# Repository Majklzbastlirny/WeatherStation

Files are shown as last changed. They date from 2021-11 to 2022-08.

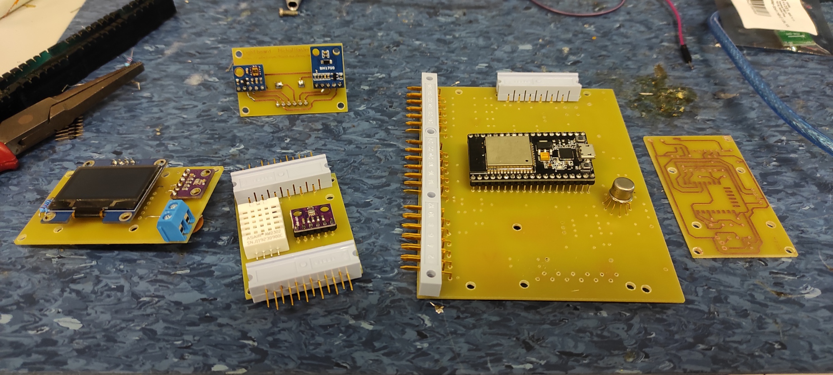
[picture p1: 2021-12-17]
Hardware/PCBs and other pcb stuff/IMG_20211216_153734.jpg

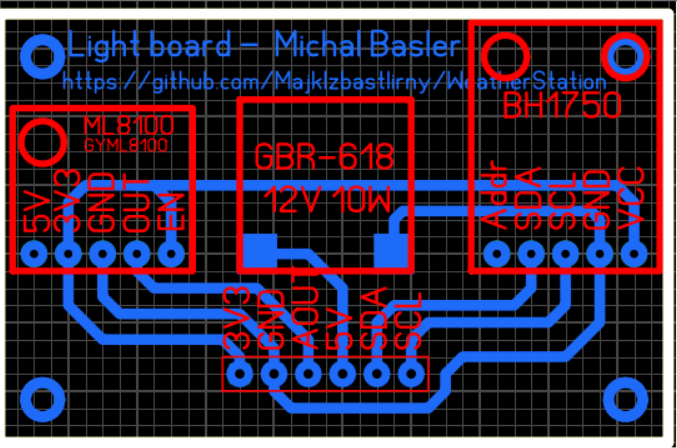
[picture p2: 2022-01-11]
Hardware/PCBs and other pcb stuff/Light board.png

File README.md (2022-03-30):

# WeatherStation
# NEEDS ESP32 ver. 2.0.0 (as Arduino board) otherwise light sensor will NOT work
Weather Station with ESP32, ESP8266, MQTT, InfluxDB and Grafana.

This is my maturita (finals) project.

Public API: https://weatherapi.majkl.tk

Public dashboard https://grafana.majkl.tk

Twitter (new data uploaded every second hour): https://twitter.com/majklzbastlirny

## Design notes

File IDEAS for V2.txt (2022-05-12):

LoRa/LoRaWan - 4 msg/hour https://avbentem.github.io/airtime-calculator/ttn/eu868/180,15
hybrid approach, software update ONLY local (station - Display), data publishing LoRaWan and Local lora to RPI (Display & DB unit)
Light sensor - VEML7700 (Vishay)
Humidity, Pressure, temperature - BME680(688) (Bosch sensortek)

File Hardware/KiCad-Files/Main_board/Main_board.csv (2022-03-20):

Source:,"C:\Users\Michal\Documents\GitHub\WeatherStation\Hardware\KiCad-Files\Main_board\Main_board.kicad_sch"
Date:,"20.03.2022 18:25:14"
Tool:,"Eeschema (6.0.0)"
Generator:,"C:\Program Files\KiCad\6.0\bin\scripting\plugins/bom_csv_grouped_by_value.py"
Component Count:,"46"
Individual Components:
 | Oznaèení | Hodnota | Název | Typ | Vırobce | Velikost
Item,"Qty","Reference(s)","Value","LibPart","Footprint","Datasheet" | B1 | 380V~/1,5A | Usmìròovaè |  |  | 9mm
,"","B1","RB1A","Main_board-eagle-import:RB1A","Diode_THT:Diode_Bridge_Round_D9.0mm","" | C1-C3 | 1mF | Elektrolityckı
,"","C1","1m","Main_board-eagle-import:CPOL-EUE2,5-6E","Capacitor_THT:CP_Radial_D12.5mm_P7.50mm","" | C4-C5 | 100nF | Keramickı kondenzátor
,"","C2","1m","Main_board-eagle-import:CPOL-EUE2,5-6E","Capacitor_THT:CP_Radial_D12.5mm_P7.50mm","" | D1-D3 | 1kV/1A | Schottkyho dioda | UF4007GP | Diotec Semiconductor
,"","C3","1m","Main_board-eagle-import:CPOL-EUE2,5-6E","Capacitor_THT:CP_Radial_D12.5mm_P7.50mm","" | R1-R7 | 43R | Metalizovanı odpor | TR191 | Tesla
,"","C4","100n","Device:C","Capacitor_THT:C_Axial_L5.1mm_D3.1mm_P12.50mm_Horizontal","~" | R8 | 9k1 | Metalizovanı odpor | TR191 | Tesla
,"","C5","100n","Device:C","Capacitor_THT:C_Axial_L5.1mm_D3.1mm_P12.50mm_Horizontal","~" | R9 | 12k | Metalizovanı odpor | TR191 | Tesla
,"","D1","1N581","Main_board-eagle-import:1N581","Diode_THT:D_A-405_P7.62mm_Horizontal","" | R10 | 130R | Metalizovanı odpor | TR191 | Tesla
,"","D2","1N581","Main_board-eagle-import:1N581","Diode_THT:D_A-405_P7.62mm_Horizontal","" | R11 | 90k9 | Metalizovanı odpor | TR191 | Tesla
,"","D3","1N581","Main_board-eagle-import:1N581","Diode_THT:D_A-405_P7.62mm_Horizontal","" | R12 | 464R | Metalizovanı odpor | TR191 | Tesla
,"","F1","2A","Main_board-eagle-import:SH25","Fuse:Fuseholder_Cylinder-5x20mm_Stelvio-Kontek_PTF78_Horizontal_Open","" | X1 |  | Wago svorka x2 |  | Wago
,"","F2","2A","Main_board-eagle-import:SH25","Fuse:Fuseholder_Cylinder-5x20mm_Stelvio-Kontek_PTF78_Horizontal_Open","" | X2,X3 |  | WK konektor samec |  | Tesla
,"","JP1","PINHD-1X1","Main_board-eagle-import:PINHD-1X1","Connector_Pin:Pin_D0.7mm_L6.5mm_W1.8mm_FlatFork","" | X4 |  | WK konektor samec trojnásobnı |  | Tesla
,"","JP2","PINHD-1X1","Main_board-eagle-import:PINHD-1X1","Connector_Pin:Pin_D0.7mm_L6.5mm_W1.8mm_FlatFork","" | LED1-LED8 | 10mA/2,5V | Zelená LED | VQA25 | Tesla
,"","JP3","PINHD-1X1","Main_board-eagle-import:PINHD-1X1","Connector_Pin:Pin_D0.7mm_L6.5mm_W1.8mm_FlatFork","" | F1-F2 | 2A-F | Pojistkové pouzdro
,"","JP4","PINHD-1X1","Main_board-eagle-import:PINHD-1X1","Connector_Pin:Pin_D0.7mm_L6.5mm_W1.8mm_FlatFork","" | Q1 |  | N-Mosfet
,"","JP5","PINHD-1X1","Main_board-eagle-import:PINHD-1X1","Connector_Pin:Pin_D0.7mm_L6.5mm_W1.8mm_FlatFork","" | U1 |  | ESP32-Devkit |  | Espressif
,"","LED1","LEDB152","Main_board-eagle-import:LEDB152","LED_THT:LED_D1.8mm_W3.3mm_H2.4mm","" | U2 |  | TSR1-2450 |  | Traco
,"","LED2","LEDB152","Main_board-eagle-import:LEDB152","LED_THT:LED_D1.8mm_W3.3mm_H2.4mm","" | U3 |  | Buck mìniè s LM2596
,"","LED3","LEDB152","Main_board-eagle-import:LEDB152","LED_THT:LED_D1.8mm_W3.3mm_H2.4mm",""
,"","LED4","LEDB152","Main_board-eagle-import:LEDB152","LED_THT:LED_D1.8mm_W3.3mm_H2.4mm",""
,"","LED5","LEDB152","Main_board-eagle-import:LEDB152","LED_THT:LED_D1.8mm_W3.3mm_H2.4mm","" | SV1 |  | WK konektor samec |  | Tesla
,"","LED6","LEDB152","Main_board-eagle-import:LEDB152","LED_THT:LED_D1.8mm_W3.3mm_H2.4mm","" | SV2-4 |  | WK konektor samec |  | Tesla
,"","LED7","LEDB152","Main_board-eagle-import:LEDB152","LED_THT:LED_D1.8mm_W3.3mm_H2.4mm","" | SV5 |  | WK konektor samec |  | Tesla
,"","LED8","LEDB152","Main_board-eagle-import:LEDB152","LED_THT:LED_D1.8mm_W3.3mm_H2.4mm","" | X1 |  | Wago svorka x2 |  | Wago
,"","Q1","N-MOSFET","Main_board-eagle-import:MOSFET-NGDS_TO220V","Package_TO_SOT_THT:TO-220-3_Horizontal_TabDown",""
,"","R1","43R","Main_board-eagle-import:R-EU_0207{slash}10","Resistor_THT:R_Axial_DIN0207_L6.3mm_D2.5mm_P10.16mm_Horizontal",""
,"","R2","43R","Main_board-eagle-import:R-EU_0207{slash}10","Resistor_THT:R_Axial_DIN0207_L6.3mm_D2.5mm_P10.16mm_Horizontal",""
,"","R3","43R","Main_board-eagle-import:R-EU_0207{slash}10","Resistor_THT:R_Axial_DIN0207_L6.3mm_D2.5mm_P10.16mm_Horizontal",""
,"","R4","43R","Main_board-eagle-import:R-EU_0207{slash}10","Resistor_THT:R_Axial_DIN0207_L6.3mm_D2.5mm_P10.16mm_Horizontal",""
,"","R5","43R","Main_board-eagle-import:R-EU_0207{slash}10","Resistor_THT:R_Axial_DIN0207_L6.3mm_D2.5mm_P10.16mm_Horizontal",""
,"","R6","43R","Main_board-eagle-import:R-EU_0207{slash}10","Resistor_THT:R_Axial_DIN0207_L6.3mm_D2.5mm_P10.16mm_Horizontal",""
,"","R7","43R","Main_board-eagle-import:R-EU_0207{slash}10","Resistor_THT:R_Axial_DIN0207_L6.3mm_D2.5mm_P10.16mm_Horizontal",""
,"","R8","9k1","Main_board-eagle-import:R-EU_0207{slash}10","Resistor_THT:R_Axial_DIN0207_L6.3mm_D2.5mm_P10.16mm_Horizontal",""
,"","R9","12k","Main_board-eagle-import:R-EU_0207{slash}10","Resistor_THT:R_Axial_DIN0207_L6.3mm_D2.5mm_P10.16mm_Horizontal",""
,"","R10","130R","Main_board-eagle-import:R-EU_0207{slash}10","Resistor_THT:R_Axial_DIN0207_L6.3mm_D2.5mm_P10.16mm_Horizontal",""
,"","R11","90K9","Main_board-eagle-import:R-EU_0207{slash}10","Resistor_THT:R_Axial_DIN0207_L6.3mm_D2.5mm_P10.16mm_Horizontal",""
,"","R12","464R","Main_board-eagle-import:R-EU_0207{slash}10","Resistor_THT:R_Axial_DIN0207_L6.3mm_D2.5mm_P10.16mm_Horizontal",""
,"","SV1","MA12-1","Main_board-eagle-import:MA12-1","Connector_PinHeader_2.54mm:PinHeader_1x12_P2.54mm_Horizontal",""
,"","SV2","MA12-1","Main_board-eagle-import:MA12-1","Connector_PinHeader_2.54mm:PinHeader_1x12_P2.54mm_Horizontal",""
,"","SV3","MA12-1","Main_board-eagle-import:MA12-1","Connector_PinHeader_2.54mm:PinHeader_1x12_P2.54mm_Horizontal",""
,"","SV4","MA12-1","Main_board-eagle-import:MA12-1","Connector_PinHeader_2.54mm:PinHeader_1x12_P2.54mm_Horizontal",""
,"","SV5","MA12-1","Main_board-eagle-import:MA12-1","Connector_PinHeader_2.54mm:PinHeader_1x12_P2.54mm_Horizontal",""
,"","U1","ESP32-DEVKITC-32D","Main_board-eagle-import:ESP32-DEVKITC-32D","ESP32:MODULE_ESP32-DEVKITC-32D",""
,"","U2","TSR1-2450","Main_board-eagle-import:TSR1-2450","Converter_DCDC:Converter_DCDC_RECOM_R-78E-0.5_THT",""
,"","U3","Buck_converter-LM2596","Buck_Converter:Buck_converter-LM2596","",""
,"","X1","W237-102","Main_board-eagle-import:W237-102","TerminalBlock_WAGO:TerminalBlock_WAGO_236-102_1x02_P5.00mm_45Degree",""
Collated Components:
Item,"Qty","Reference(s)","Value","LibPart","Footprint","Datasheet"
1,"1","B1","RB1A","Main_board-eagle-import:RB1A","Diode_THT:Diode_Bridge_Round_D9.0mm",""
2,"3","C1, C2, C3","1m","Main_board-eagle-import:CPOL-EUE2,5-6E","Capacitor_THT:CP_Radial_D12.5mm_P7.50mm",""
3,"2","C4, C5","100n","Device:C","Capacitor_THT:C_Axial_L5.1mm_D3.1mm_P12.50mm_Horizontal","~"
4,"3","D1, D2, D3","1N581","Main_board-eagle-import:1N581","Diode_THT:D_A-405_P7.62mm_Horizontal",""
5,"2","F1, F2","2A","Main_board-eagle-import:SH25","Fuse:Fuseholder_Cylinder-5x20mm_Stelvio-Kontek_PTF78_Horizontal_Open",""
6,"5","JP1, JP2, JP3, JP4, JP5","PINHD-1X1","Main_board-eagle-import:PINHD-1X1","Connector_Pin:Pin_D0.7mm_L6.5mm_W1.8mm_FlatFork",""
7,"8","LED1, LED2, LED3, LED4, LED5, LED6, LED7, LED8","LEDB152","Main_board-eagle-import:LEDB152","LED_THT:LED_D1.8mm_W3.3mm_H2.4mm",""
8,"1","Q1","N-MOSFET","Main_board-eagle-import:MOSFET-NGDS_TO220V","Package_TO_SOT_THT:TO-220-3_Horizontal_TabDown",""
9,"7","R1, R2, R3, R4, R5, R6, R7","43R","Main_board-eagle-import:R-EU_0207{slash}10","Resistor_THT:R_Axial_DIN0207_L6.3mm_D2.5mm_P10.16mm_Horizontal",""
10,"1","R8","9k1","Main_board-eagle-import:R-EU_0207{slash}10","Resistor_THT:R_Axial_DIN0207_L6.3mm_D2.5mm_P10.16mm_Horizontal",""
11,"1","R9","12k","Main_board-eagle-import:R-EU_0207{slash}10","Resistor_THT:R_Axial_DIN0207_L6.3mm_D2.5mm_P10.16mm_Horizontal",""
12,"1","R10","130R","Main_board-eagle-import:R-EU_0207{slash}10","Resistor_THT:R_Axial_DIN0207_L6.3mm_D2.5mm_P10.16mm_Horizontal",""
13,"1","R11","90K9","Main_board-eagle-import:R-EU_0207{slash}10","Resistor_THT:R_Axial_DIN0207_L6.3mm_D2.5mm_P10.16mm_Horizontal",""
14,"1","R12","464R","Main_board-eagle-import:R-EU_0207{slash}10","Resistor_THT:R_Axial_DIN0207_L6.3mm_D2.5mm_P10.16mm_Horizontal",""
15,"5","SV1, SV2, SV3, SV4, SV5","MA12-1","Main_board-eagle-import:MA12-1","Connector_PinHeader_2.54mm:PinHeader_1x12_P2.54mm_Horizontal",""
16,"1","U1","ESP32-DEVKITC-32D","Main_board-eagle-import:ESP32-DEVKITC-32D","ESP32:MODULE_ESP32-DEVKITC-32D",""
17,"1","U2","TSR1-2450","Main_board-eagle-import:TSR1-2450","Converter_DCDC:Converter_DCDC_RECOM_R-78E-0.5_THT",""
18,"1","U3","Buck_converter-LM2596","Buck_Converter:Buck_converter-LM2596","",""
19,"1","X1","W237-102","Main_board-eagle-import:W237-102","TerminalBlock_WAGO:TerminalBlock_WAGO_236-102_1x02_P5.00mm_45Degree",""

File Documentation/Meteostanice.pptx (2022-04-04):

## Meteostanice

Michal Basler E4 – 2021/2022

## Co vše v téhle prezentaci bude?

- Průběh práce
- Popis jednotlivých součástí
- Popis kódu
- Výsledek

## Jak práce probíhala

- Prototypování na nepájivém poli
- Nakreslení desek a jejich osazení
- Zkouška všech modulů
- Tisk fyzických součástí
- Složení a oživení

## Co stanice umí měřit

- Stanice umí měřit teplotu, absolutní tlak, relativní vlhkost, UV intenzitu, světelnou intenzitu, směr větru a rychlost větru.
- Dále umí vypočítat pocitovou teplotu, rosný bod, relativní tlak a větrný chlad

## Anemometr

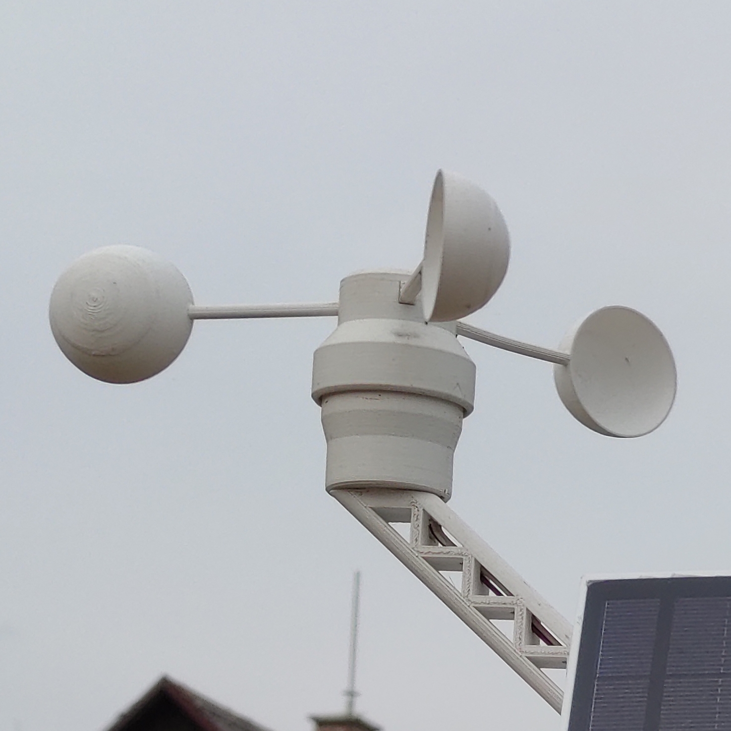
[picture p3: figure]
Anemometr, který je nachází v práci.
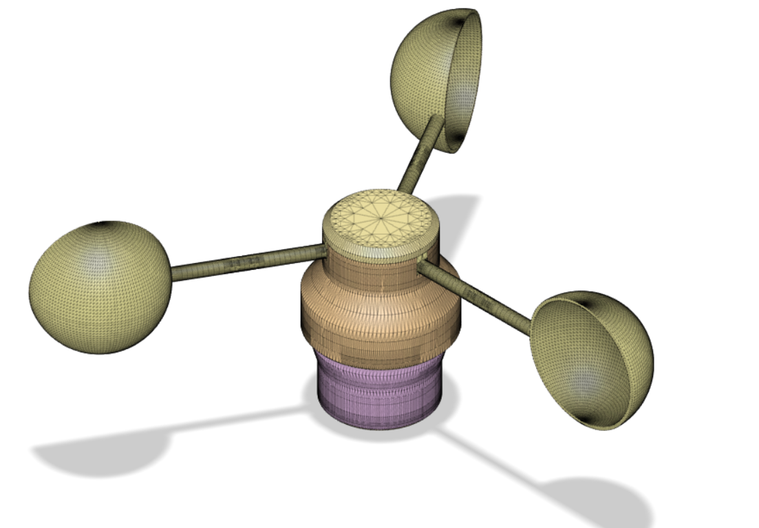
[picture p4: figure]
3D model anemometru

## Korouhev

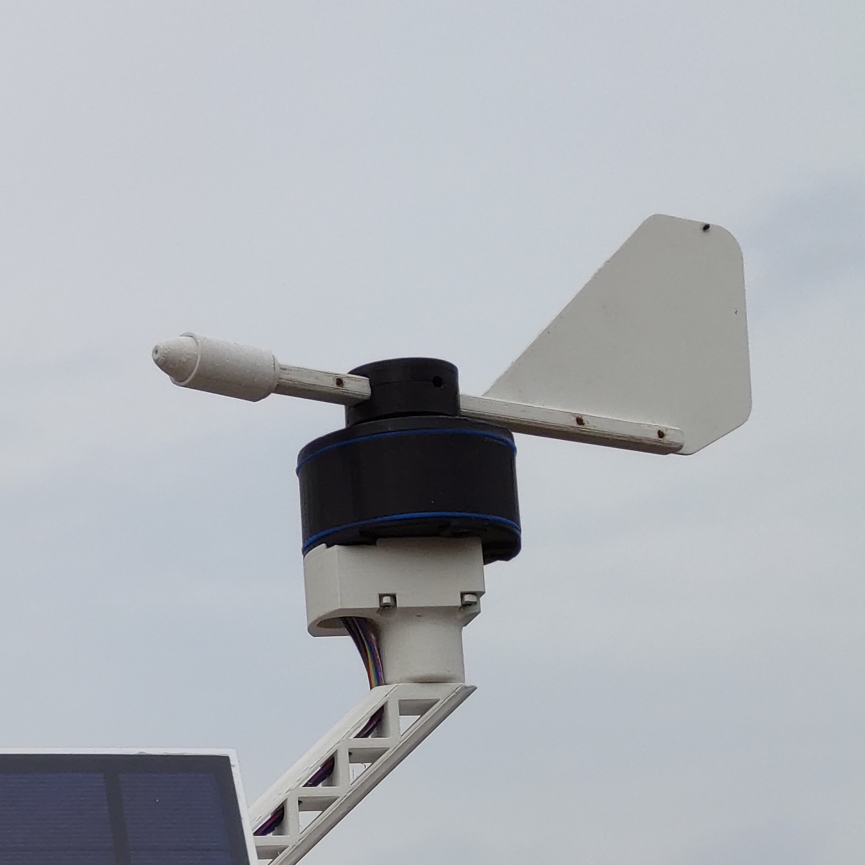
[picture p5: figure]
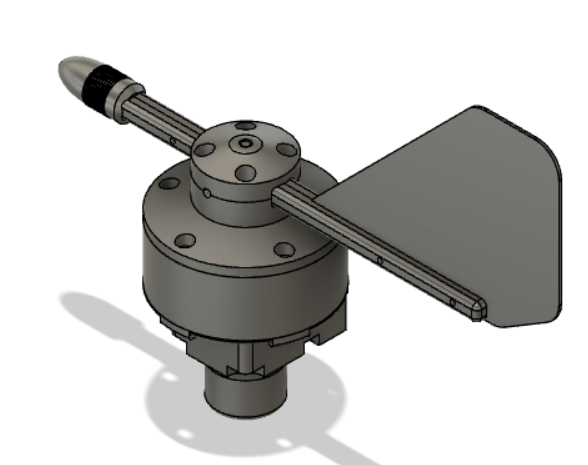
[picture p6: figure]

## Senzory

## Deska senzorů 1

## Deska senzorů 2

## Popis fungování stanice

## Popis fungování zobrazovačů

## Grafana

## API

## Twitter bot

## Výsledek

## Shrnutí

## Díky za pozornost

- Nyní nastal čas na Vaše otázky

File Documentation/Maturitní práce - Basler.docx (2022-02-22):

Vyšší odborná škola a Střední průmyslová škola, Šumperk

Gen. Krátkého 1, 787 29 Šumperk

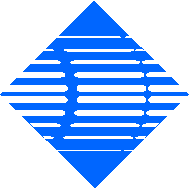
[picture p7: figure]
LOGO

Obor vzdělání: 26-41-M/01 Elektrotechnika

MATURITNÍ PRÁCE

Meteostanice

Školní rok 2021/2022 Michal Basler

Vyšší odborná škola a Střední průmyslová škola, Šumperk,

Gen. Krátkého 1, 787 29 Šumperk

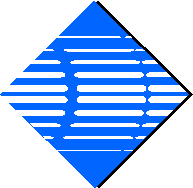
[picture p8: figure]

Obor vzdělání: 26-41-M/01 Elektrotechnika

ZADÁNÍ MATURITNÍ PRÁCE

z odborných předmětů

Žák/Žákyně: Michal Basler

Téma maturitní práce: Meteostanice

Obsah maturitní práce: 1. Základní informace

2. Elektronika a zapojení

3. Kód

Datum zadání: 30. září 2021

Datum odevzdání: 25. března 2022

Vedoucí práce: PaedDr. SOURAL Martin, MBA Podpis:

Prohlášení

Prohlašuji, že jsem svou maturitní práci vypracoval samostatně a použil jsem pouze prameny a literaturu uvedené v seznamu bibliografických záznamů.

Prohlašuji, že tištěná verze a elektronická verze maturitní práce jsou shodné.

Nemám závažný důvod proti zpřístupňování této práce v souladu se zákonem č. 121/2000 Sb., o právu autorském, o právech souvisejících s právem autorským a o změně některých zákonů (autorský zákon) ve znění pozdějších předpisů.

V Šumperku dne datum ……………………………………………………

Michal Basler

Poděkování

Děkuji všem, co mi nepomohli

Vyšší odborná škola a Střední průmyslová škola, Šumperk,

Gen. Krátkého 1, 787 29 Šumperk

KONZULTAČNÍ LIST

Žák/Žákyně: Michal Basler Třída: E4

Téma maturitní práce: Meteostanice

_________________________________________________________________________

Datum kontroly: _________________

Obsah kontroly: ________________________________________________________

Hodnocení kontroly: 1 2 3 4 5 Podpis vedoucího práce: ________

Datum kontroly: _________________

Obsah kontroly: ________________________________________________________

Hodnocení kontroly: 1 2 3 4 5 Podpis vedoucího práce: ________

Datum kontroly: _________________

Obsah kontroly: ________________________________________________________

Hodnocení kontroly: 1 2 3 4 5 Podpis vedoucího práce: ________

Datum kontroly: _________________

Obsah kontroly: ________________________________________________________

Hodnocení kontroly: 1 2 3 4 5 Podpis vedoucího práce: ________

Datum kontroly: _________________

Obsah kontroly: ________________________________________________________

Hodnocení kontroly: 1 2 3 4 5 Podpis vedoucího práce: ________

Obsah vygenerujte!

# 1 Úvod

Práce se zabývá návrhem, výrobou, konstrukcí a zprovozněním poloprofesionální meteostanice vyrobené s použitím to 3D tisku.

Meteostanice by měla umět měřit základní veličiny a to teplota, tlak, vlhkost, rychlost větru, směr větru, UV intenzitu a světlo. Meteostanice by z naměřených jednotek měla také odvodit rosný bod, pocitovou teplotu a relativní tlak.

Cílem mé maturitní práce je zprovoznění meteostanice a zveřejnění měřených dat na internet.

# 2 Meteorologická stanice

Meteorologické stanice jsou zařízení, které umožňují lidem zjišťovat aktuální a budoucí počasí.

Ve většině domácností se tahle zařízení nacházejí, ale umí měřit pouze základní údaje jako je teplota, vlhkost a tlak. Navíc také data zobrazují pouze na jednoúčelových obrazovkách a není zde možnost je zobrazit třeba na mobilním telefonu.

Profesionální stanice měří navíc i rychlost a směr větru, UV záření, sluneční záření, množství srážek, množství oblačnosti a mnoho dalších jevů.

## 2.1 Druhy senzorů

Zde popíšu principy a zařízení, kterými se měří jednotlivé veličiny. Z důvodu, že se jedná o elektrické zařízení, budou zde jmenováno pouze elektrická měření těchto veličin.

### Teploměr

Teplotu lze změřit mnoha různými způsoby. Mezi ně patří třeba měření pozistorem, termočlánkem, negistorem anebo polovodičem. Negistoru se při rostoucí teplotě snižuje odpor. U pozistorů odpor naopak roste. U termočlánků se při rostoucí teplotě zvyšuje proud. Termočlánky se skládají ze dvou různých kovů. Díky tomu termočlánky vydrží i velice vysoké teploty.

### Vlhkoměr

Čistě elektronicky lze měřit relativní vlhkost pouze kapacitně a odporově. U kapacitních se uvnitř nachází dvě elektrody a oddělující vrstva z hygroskopického materiálu. Mezi elektrodami se měří napětí, a to je dále posíláno na zpracovaní na užitečný údaj. U odporových vlhkoměrů se mění odpor v závislosti na vlhkosti. Uvnitř se nachází materiál, který absorbuje vlhkost a přes něj se měří odpor. Výsledná jednotka je udávána jako relativní vlhkost v %.

### Tlakoměr

Tlak lze elektronicky změřit mnoha způsoby. Jednou z nejrozšířenější metod měření tlaku je měření tenzometrem. Jedná se o tenkou kovovou folii přilepenou na membránu. Membrána se pohybuje v závislosti na tlaku a tím se pohybuje i kovová folie. Na ní se měří odpor a ten je následně převáděn tlak. Měřit tlak lze i za pomocí piezorezistivního tenzometru. Využívá se piezoelektrického efektu.

### Anemometr

Anemometr, anebo měřič rychlosti větru se používá na měření rychlosti větru. Elektronicky lze rychlost větru měřit buď dynamem, anebo „tachometrem“. U měření rychlosti dynamem se používá malý motorek jako generátor. V závislosti na rychlosti větru se generuje napětí. Generované napětí je převáděno pomocí A/D převodníku na signál, který lze už převést na rychlost větru. U měření rychlosti „tachometrem“ se používá v anemometru magnet a Hallova sonda nebo jazýčkové relé. Při jednom otočení magnet aktivuje Hallovu sondu anebo jazýčkové relé. Mikropočítač tyto impulzy vezme a s pomocí průměru anemometru vypočítá přesně rychlost větru.

### Větrná korouhev

Větrná korouhev se používá k určení směru větru. Vítr natáčí korouhví a vnitřní obvody detekují směr větru. Směr lze detekovat buď pomocí mnoha jazýčkových relé nebo Hallových sond, ale tahle cesta umožňuje pouze měřit málo přesně. Šlo by rozpoznat pouze sever, severovýchod, východ, jihovýchod, … Z tohoto důvodu jsem se rozhodl jít druhou cestou, a to je cesta pomocí enkodéru. Uvnitř korouhve se nachází disk s otvory. Skrze ně svítí světlo na senzory. Z počtu zakrytých senzorů lze velice přesně vyvodit úhel větru. Tahle cesta je i levnější.

### Srážkoměr

Tento senzor se používá na měření srážek. Nejjednodušší cesta na měření srážek je překlápěcí nádobka. Nádobka se skládá ze dvou symetrických částí. Když do 1. nádobky nateče určité množství vody, tak se nádobka překlopí. Toto překlopení zaregistruje procesor, který si počet překlopení zapamatuje. Po překlopení se 1. část vyprázdní. Následně natéká voda do 2. nádobky. Když do ní nateče stejné množství vody, tak se překlopí zpět, procesor zaregistruje další překlopení, voda odteče a vše může začít znovu.

## 2.2 Popis jednotlivých senzorů na mé stanici

### Teploměr a tlakoměr

Jako senzor teploty, tlaku a vlhkosti jsem zvolil BME280 a BMP280 od firmy Bosch Sensortek. Tento čip byl zvolen z toho důvodu, že komunikace s ním po sběrnici I2C je velice snadná. Z důvodu stále probíhajícího nedostatku čipů se první prototyp stavěl s jeho ekvivalentem a to BMP180. Čip BMP280 se nachází jak ve vnitřních jednotkách, tak i ve venkovní. U malé vnitřní jednotky je měřena pouze teplota, u velké vnitřní jednotky je navíc měřena i relativní vlhkost. U venkovní jednotky měří pouze tlak a teplotu.

### Vlhkoměr

Jako vlhkoměr byl zvolen senzor DHT22. Tento senzor lze použít i jako teploměr, ale v mé stanici bude použit pouze jako vlhkoměr. Teploměrem v tomto senzoru je termistor a čas, který potřebuje k ustálení je v mém případě až moc velký. S procesorem komunikuje pomocí jednoho vodiče a tím pádem je komunikace s ním bez správné knihovny náročná. Výsledná vlhkost je zobrazena v %, jelikož senzor neměří vlhkost, ale relativní vlhkost, což je jiná veličina.

### Větrná korouhev

První ze dvou senzorů, které byly vytištěny na 3D tiskárně. V otočné části se nachází 2 magnety, které spínají Hallovu sondu ve spodní části. Použitím 2 magnetů lze zajistit přesnější měření. Pomocí matematiky lze jednoduše odvodit, jakou rychlostí fouká vítr

### Anemometr

Anemometr je druhým senzorem, který byl vytištěn na 3D tiskárně. Na zjištění úhlu se zde používá jednořádkový Grayův kód. Díky němu lze s pomocí pěti čidel získat až 30 různých poloh, každá o 12 stupňů větší.

### Senzor UV intenzity

Jako UV senzor byl zvolen čip MP8511. Tento čip je stavěn na detekci UVA a UVB záření (284-390nm). Jelikož senzor posílá data analogově, tak jejich interpretace je s pomocí procesoru velice jednoduchá. Po zpracování je výsledkem hodnota v mW/m². Z téhle hodnoty lze následně vypočítat UV index.

### Senzor světla

Posledním senzorem je senzor světla. Byl použit čip BH1750. S pomocí tohoto senzoru je stanice schopna zjistit míru osvětlení.

# 3 Popis elektrických obvodů a desek

Většina komponentů, které se na deskách nachází jsou ve formě modulů. Moduly byly zvoleny z toho důvodu, že moduly jsou jednodušší na sehnání než samostatné čipy. Kupříkladu je tu čip BME280. Tento čip se v době psaní této práce nedá samostatně nikde sehnat, tak musel být koupen ve formě modulu.

## 3.1 Základní deska

Základní deska se stará o spojení všech senzorů k procesoru a také o jejich napájení.

### Procesor

Jako hlavní procesor jsem zvolil mikrokontroler ESP32 od firmy Espressif. Byl zvolen z mnoha důvodů. Mezi ně patří třeba Wi-Fi připojení, mnoho použitelných pinů pro periferie a taky dvě použitelná jádra na zrychlení výpočtů. Pro jednodušší vývoj jsem zvolil mikrokontroler, který byl již osazen na vývojové desce s nezbytnými komunikačními čipy.

### Indikační LED diody

Pro anemometr a korouhev jsou na základní desce indikační LED diody. Tyto LED diody slouží pouze jako indikace stavů jednotlivých senzorů.

### Napájení

Napájení bylo jednou z nejobtížnějších věcí na této stanici. Musel jsem zajistit, aby se převod z 12 voltů od solárních panelů na 6v pro olověný akumulátor byl co nejefektivnější. Originálně měl na desce být osazen lineární regulátor MAA723 od bývalé Tesly Rožnov. Ale jelikož se jedná o lineární regulátor, tak by jeho ztráty byly vyšší než vlastní spotřeba celého zařízení. Proto jsem se rozhodl lineární cestu opustit a místo něj sem osadil spínaný modul s LM2396, který má převést napětí až s 90 % efektivitou. Z 6 voltů z akumulátoru jsem potřeboval získat 5 voltů pro mikroprocesor. Zde byl zvolen spínaný stabilizátor napětí TSR 1-2450 firmy Traco Power. O napětí 3,3 voltů pro jednotlivé instrumenty se stará modul s procesorem.

### Spínací obvody

Aby senzory a vytápěcí obvody nejely nonstop, tak byly na základní desku dány obvody pro jejich spínání, kdy je potřeba. Tím docílím vyšší výdrže baterie. Pro spínání senzorů byl zvolen MOSFET a pro mnohem náročnější vytápění bylo relé tou správnou volbou.

### Akumulátor

Jako úložiště energie byl vybrán 6 V olověný gelový akumulátor. Tento typ akumulátorů je stavěn na drsnější podmínky. Pro měření napětí je na desce také jednoduchý dělič napětí, jehož výsledné napětí je měřeno jedním z analogových vstupů na procesoru.

## 3.2 Deska senzorů 1

Úkolem této desky je sbírat data o teplotě, tlaku a relativní vlhkosti.

Tlak a teplotu snímá senzor BMP280. Vlhkost snímá senzor DHT22.

## 3.3 Deska senzorů 2

Tato deska má za úkol měřit světlo. Jak UV intenzitu, tak i světelnost. Deska je také osazena vyhřívacím odporem. Ten je přilepen na okénko, skrz které senzory vidí na oblohu. Pokud je okénko zasněžené, vyhřívací odpor začne topit a sníh roztaje. Tak je možno měřit světelnost i v zimě.

## 3.4 Vnitřní jednotka s OLED displejem

Jako první z mnoha přídavků ke stanici jsem vyrobil vnitřní jednotku. Uvnitř je pouze procesor ESP8266, OLED displej a stejný senzor teploty a tlaku BMP280. Opět zde mohl být použit senzor BME280, ale nejsou dostupné, takže vlhkost uvnitř nelze měřit. Tato jednotka zobrazí nejnovější data ze stanice.

## 3.5 Vnitřní jednotka s E-INK displejem.

Tenhle přídavek byl koupen jako celek, kromě baterie a krabičky. Úkolem této vnitřní jednotky je zobrazit data, která jsou až 24hodin stará. Výhodou E-INK displejů je ta, že mohou data zobrazovat i bez elektřiny.

# 4 programy a kód

Kód je nejdůležitější částí této stanice. Bez něj by nic nefungovalo. Z důvodu velice dlouhých kódů budou u některých částí odkazy na GitHub, kde se kód nachází.

## 4.1 Kód pro stanici

Lorem

## 4.2 Kód pro OLED zobrazovače

Ipsum

## 4.3 Kód E-INK zobrazovač

Dolor

## 4.4 Překladatel

Sit

## 4.5 Veřejný přístup

Amet

### Grafana

Consectetuer

### API

Adipiscing

### Twitter

Elit

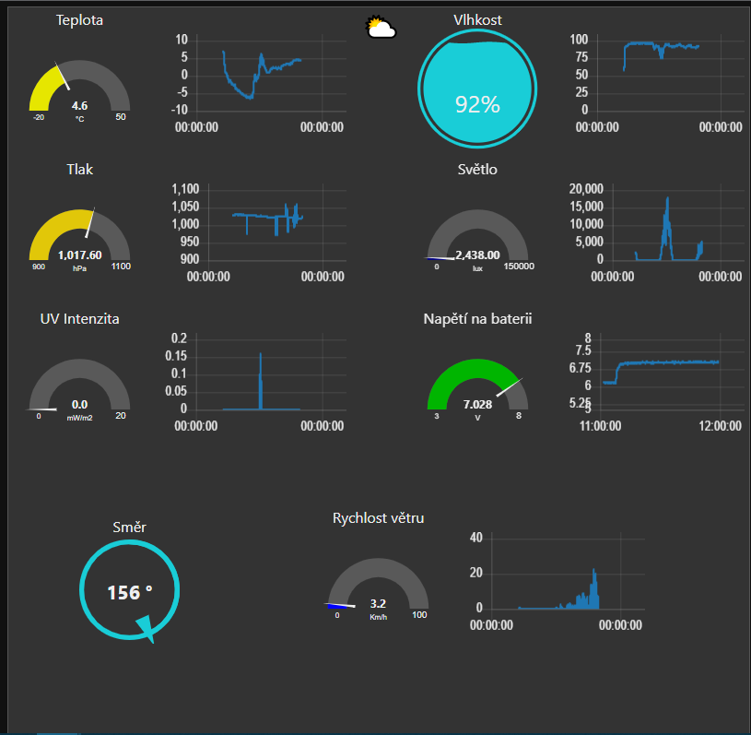
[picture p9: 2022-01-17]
Hardware/PCBs and other pcb stuff/Snímek obrazovky 2022-01-17 114043.png

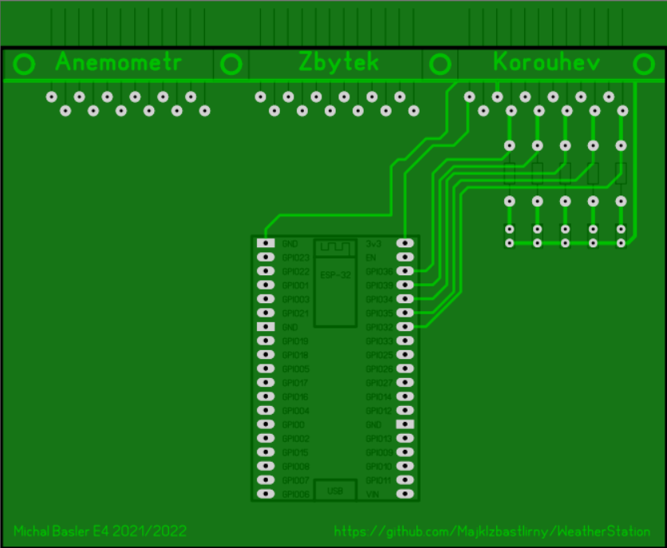
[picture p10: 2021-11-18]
Hardware/PCBs and other pcb stuff/Bottom_18.11.21.png

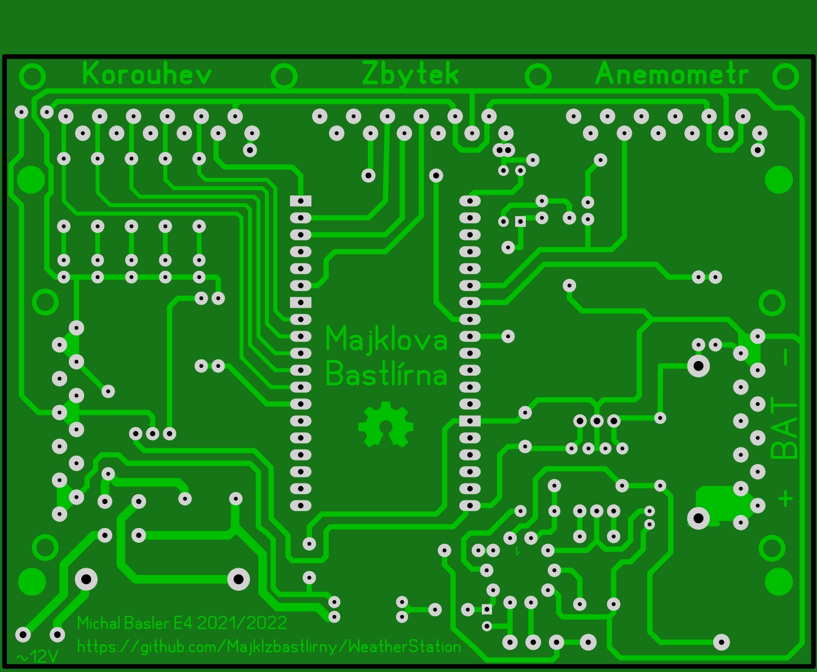
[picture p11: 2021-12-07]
Hardware/PCBs and other pcb stuff/Bottom_7.12..JPG

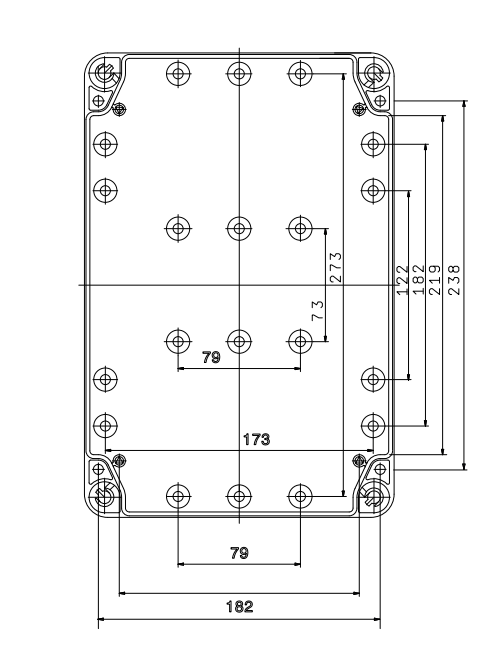
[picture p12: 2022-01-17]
Hardware/PCBs and other pcb stuff/Snímek obrazovky 2022-01-13 125437.png

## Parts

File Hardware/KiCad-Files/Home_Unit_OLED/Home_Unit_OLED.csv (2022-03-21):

Source: | C:\Users\Michal\Documents\GitHub\WeatherStation\Hardware\KiCad-Files\Home_Unit_OLED\Home_Unit_OLED.kicad_sch
Date: | 21.03.2022 11:05:10
Tool: | Eeschema (6.0.0)
Generator: | C:\Program Files\KiCad\6.0\bin\scripting\plugins/bom_csv_grouped_by_value.py
Component Count: | 14
Individual Components:
Item | Qty | Reference(s) | Value | LibPart | Footprint | Datasheet | PROD_ID
 |  | A1 | BMP(E)_180(280) | BMP(E)_180(280):BMP(E)_180(280)
 |  | C1 | 100n | Device:C |  | ~
 |  | C2 | 100n | Device:C |  | ~
 |  | J1 | Conn_01x02 | Connector_Generic:Conn_01x02 |  | ~
 |  | J2 | Conn_01x06 | Connector_Generic:Conn_01x06 |  | ~
 |  | J3 | Conn_01x04 | Connector_Generic:Conn_01x04 |  | ~
 |  | R1 | 10k | Device:R |  | ~
 |  | R2 | 10k | Device:R |  | ~
 |  | R3 | 10k | Device:R |  | ~
 |  | R4 | 10k | Device:R |  | ~
 |  | SW1 | FLASH | Switch:SW_MEC_5E |  | http://www.apem.com/int/index.php?controller=attachment&id_attachment=1371
 |  | SW2 | RESET | Switch:SW_MEC_5E |  | http://www.apem.com/int/index.php?controller=attachment&id_attachment=1371
 |  | U1 | AMS1117-3.3 | Regulator_Linear:AMS1117-3.3 | Package_TO_SOT_SMD:SOT-223-3_TabPin2 | http://www.advanced-monolithic.com/pdf/ds1117.pdf
 |  | U2 | ESP-12S | ESP-12S:ESP-12S | ESP-12S |  | IC-14115
Collated Components:
Item | Qty | Reference(s) | Value | LibPart | Footprint | Datasheet | PROD_ID
1 | 1 | A1 | BMP(E)_180(280) | BMP(E)_180(280):BMP(E)_180(280)
2 | 2 | C1, C2 | 100n | Device:C |  | ~
3 | 1 | J1 | Conn_01x02 | Connector_Generic:Conn_01x02 |  | ~
4 | 1 | J2 | Conn_01x06 | Connector_Generic:Conn_01x06 |  | ~
5 | 1 | J3 | Conn_01x04 | Connector_Generic:Conn_01x04 |  | ~
6 | 4 | R1, R2, R3, R4 | 10k | Device:R |  | ~
7 | 1 | SW1 | FLASH | Switch:SW_MEC_5E |  | http://www.apem.com/int/index.php?controller=attachment&id_attachment=1371
8 | 1 | SW2 | RESET | Switch:SW_MEC_5E |  | http://www.apem.com/int/index.php?controller=attachment&id_attachment=1371
9 | 1 | U1 | AMS1117-3.3 | Regulator_Linear:AMS1117-3.3 | Package_TO_SOT_SMD:SOT-223-3_TabPin2 | http://www.advanced-monolithic.com/pdf/ds1117.pdf
10 | 1 | U2 | ESP-12S | ESP-12S:ESP-12S | ESP-12S |  | IC-14115

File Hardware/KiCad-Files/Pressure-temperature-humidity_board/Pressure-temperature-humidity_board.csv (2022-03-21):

Source: | C:\Users\Michal\Documents\GitHub\WeatherStation\Hardware\KiCad-Files\Pressure-temperature-humidity_board\Pressure-temperature-humidity_board.kicad_sch
Date: | 21.03.2022 10:10:33
Tool: | Eeschema (6.0.0)
Generator: | C:\Program Files\KiCad\6.0\bin\scripting\plugins/bom_csv_grouped_by_value.py
Component Count: | 6
Individual Components:
Item | Qty | Reference(s) | Value | LibPart | Footprint | Datasheet
 |  | A1 | BMP(E)_180(280) | BMP(E)_180(280):BMP(E)_180(280) | Connector_PinHeader_2.54mm:PinHeader_1x06_P2.54mm_Vertical
 |  | A2 | DHT22 | DHT22:DHT22 | Sensor:Aosong_DHT11_5.5x12.0_P2.54mm
 |  | C1 | 100u | Device:C_Polarized | Capacitor_THT:C_Disc_D12.5mm_W5.0mm_P7.50mm | ~
 |  | R1 | 10k | Device:R | Resistor_THT:R_Axial_DIN0207_L6.3mm_D2.5mm_P10.16mm_Horizontal | ~
 |  | X1 | Conn_01x12 | Connector_Generic:Conn_01x12 | Connector_PinHeader_2.54mm:PinHeader_1x12_P2.54mm_Horizontal | ~
 |  | X2 | Conn_01x12 | Connector_Generic:Conn_01x12 | Connector_PinHeader_2.54mm:PinHeader_1x12_P2.54mm_Horizontal | ~
Collated Components:
Item | Qty | Reference(s) | Value | LibPart | Footprint | Datasheet
1 | 1 | A1 | BMP(E)_180(280) | BMP(E)_180(280):BMP(E)_180(280) | Connector_PinHeader_2.54mm:PinHeader_1x06_P2.54mm_Vertical
2 | 1 | A2 | DHT22 | DHT22:DHT22 | Sensor:Aosong_DHT11_5.5x12.0_P2.54mm
3 | 1 | C1 | 100u | Device:C_Polarized | Capacitor_THT:C_Disc_D12.5mm_W5.0mm_P7.50mm | ~
4 | 1 | R1 | 10k | Device:R | Resistor_THT:R_Axial_DIN0207_L6.3mm_D2.5mm_P10.16mm_Horizontal | ~
5 | 2 | X1, X2 | Conn_01x12 | Connector_Generic:Conn_01x12 | Connector_PinHeader_2.54mm:PinHeader_1x12_P2.54mm_Horizontal | ~

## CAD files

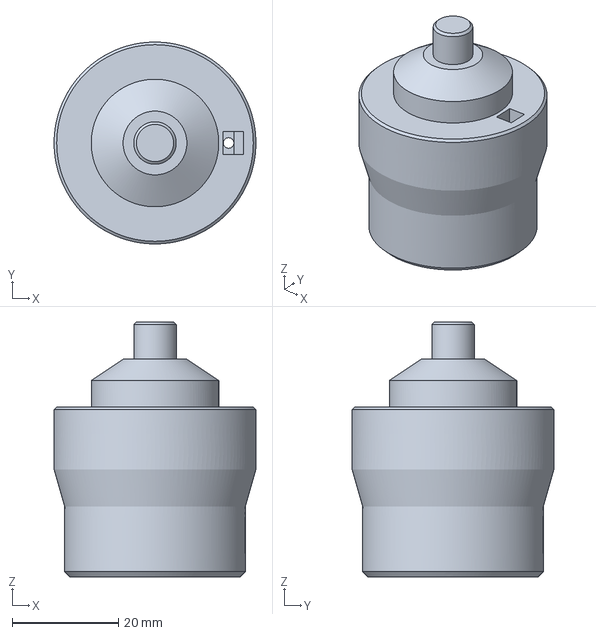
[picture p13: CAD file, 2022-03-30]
Hardware/3D files/Anemometr/Anemometr - Základna.3mf
38.0 x 38.0 x 48.0 mm

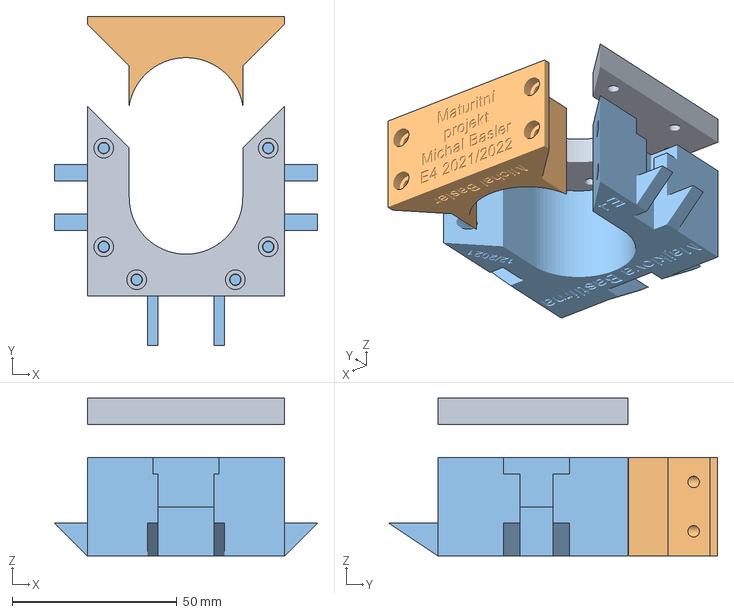
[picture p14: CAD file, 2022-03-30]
Hardware/3D files/Držáky senzorů/Držáky senzorů - Spojovač.3mf
80.0 x 100.0 x 48.0 mm

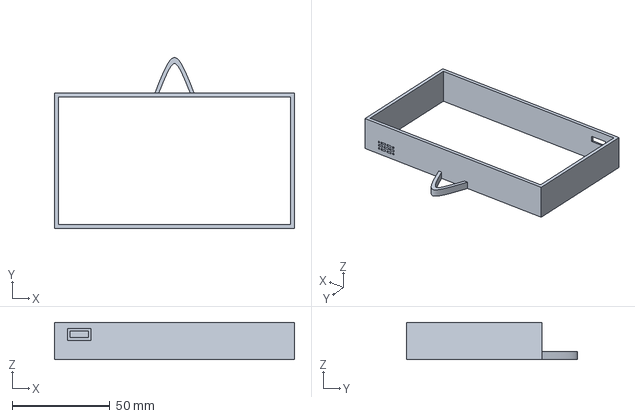
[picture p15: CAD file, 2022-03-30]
Hardware/3D files/E-Ink zobrazovač/E-Ink zobrazovač - Rámeček.3mf
123.0 x 87.6 x 19.0 mm

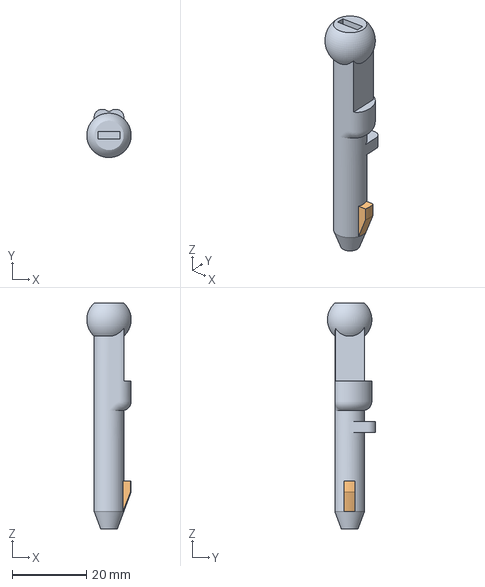
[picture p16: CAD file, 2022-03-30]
Hardware/3D files/Hlavní krabice/Hlavní krabice - Náhradní díl.3mf
12.0 x 13.0 x 61.0 mm

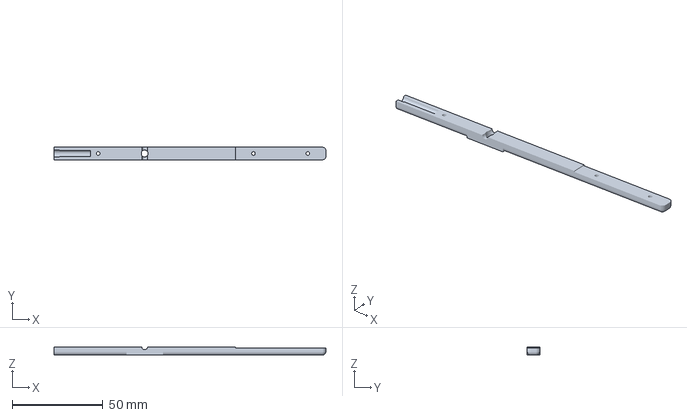
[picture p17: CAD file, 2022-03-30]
Hardware/3D files/Korouhev/Korouhev - Tyč.3mf
150.0 x 7.00 x 4.50 mm

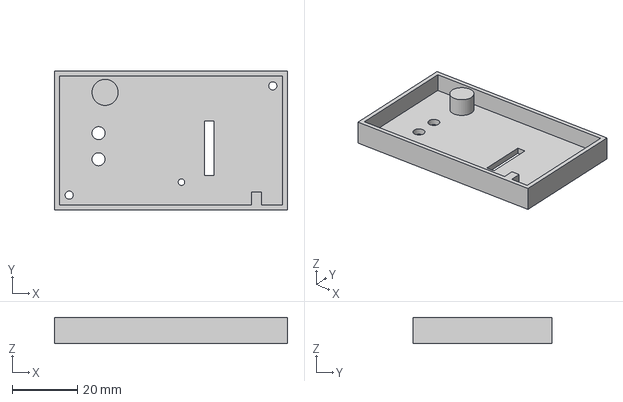
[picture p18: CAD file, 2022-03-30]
Hardware/3D files/OLED Zobrazovač/OLED Zobrazovač - Spodek.3mf
71.4 x 42.5 x 8.00 mm

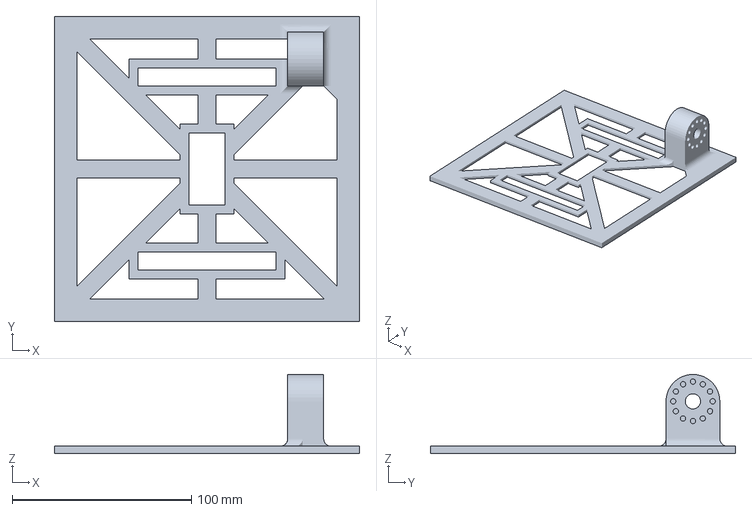
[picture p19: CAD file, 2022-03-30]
Hardware/3D files/Solární panely/Solární panel - Pravý držák.3mf
170.0 x 170.0 x 44.1 mm

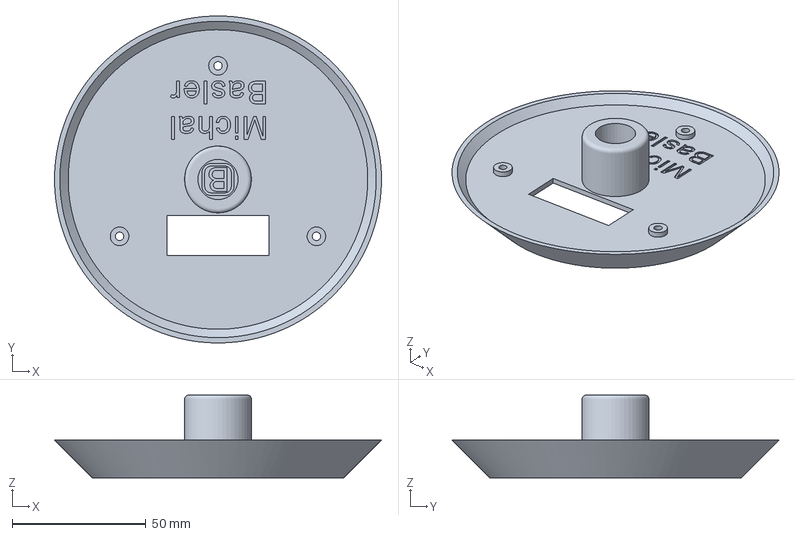
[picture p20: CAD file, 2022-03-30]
Hardware/3D files/Štít/Štít - Spodek.3mf
122.3 x 122.3 x 31.0 mm

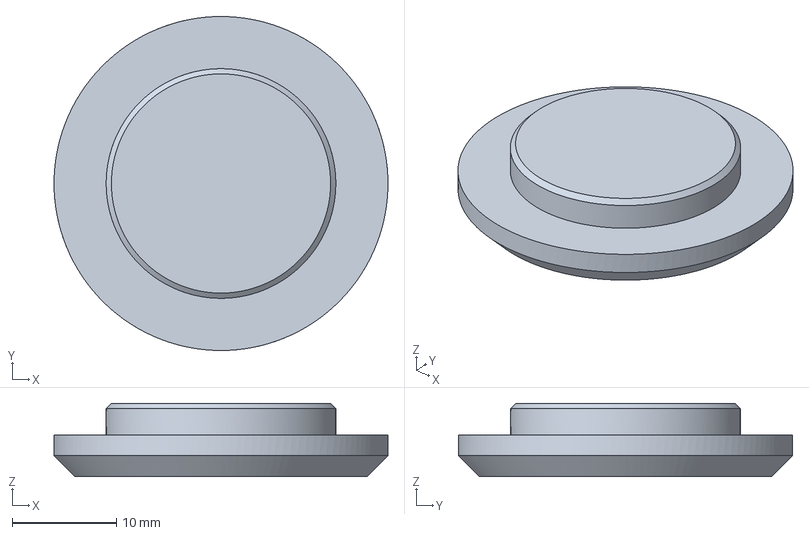
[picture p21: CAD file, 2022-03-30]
Hardware/3D files/Anemometr/Anemometr - Kryt.3mf
32.0 x 32.0 x 7.00 mm

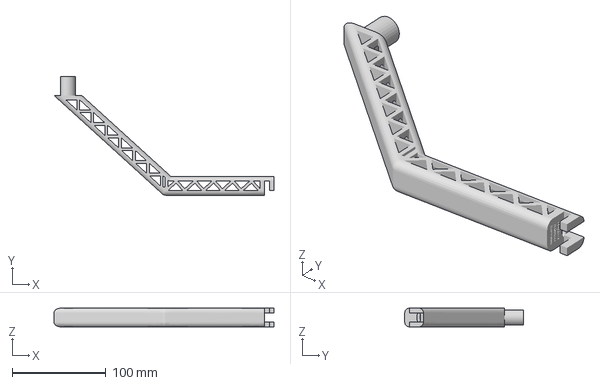
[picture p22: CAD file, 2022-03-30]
Hardware/3D files/Držáky senzorů/Držáky senzorů - Korouhev.3mf
235.0 x 126.6 x 20.0 mm

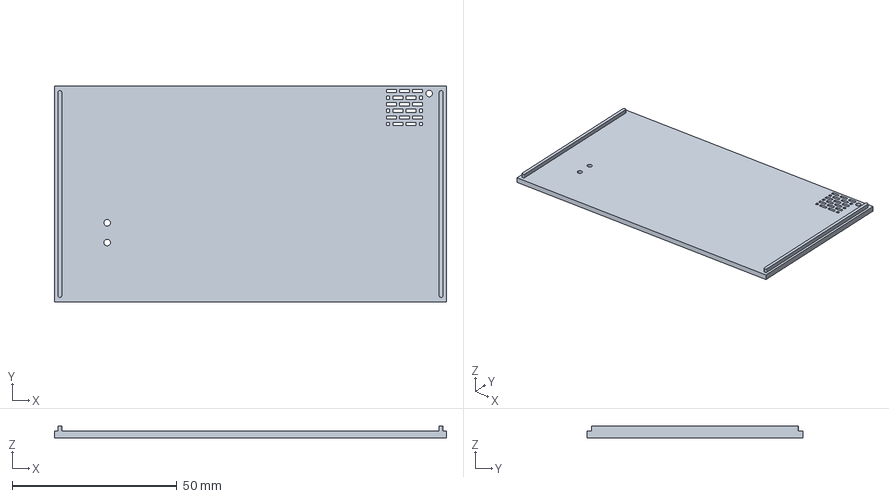
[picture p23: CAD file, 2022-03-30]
Hardware/3D files/E-Ink zobrazovač/E-Ink zobrazovač - Spodek.3mf
119.0 x 65.5 x 3.50 mm

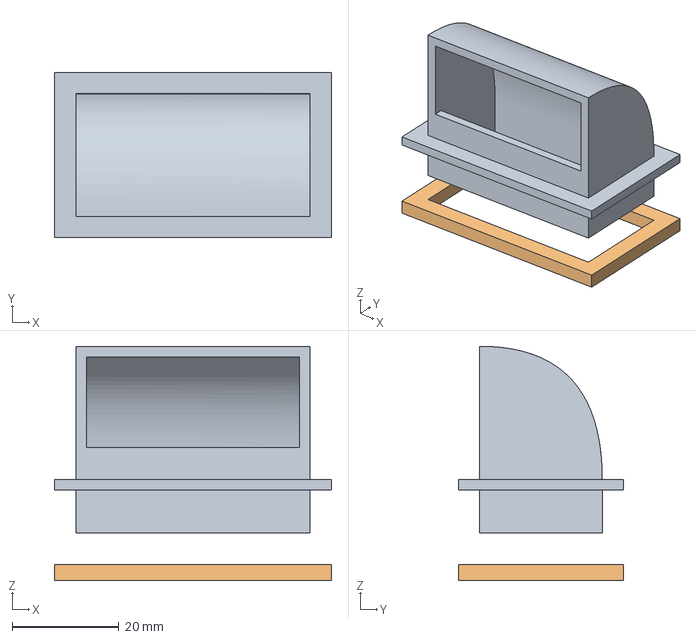
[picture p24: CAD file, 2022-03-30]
Hardware/3D files/Hlavní krabice/Hlavní krabice - Průchodka.3mf
52.0 x 31.0 x 44.0 mm

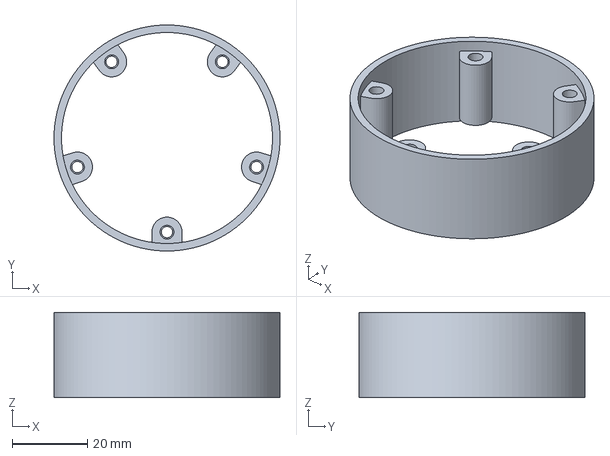
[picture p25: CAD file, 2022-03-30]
Hardware/3D files/Korouhev/Korouhev - Tělo.3mf
60.0 x 60.0 x 22.6 mm

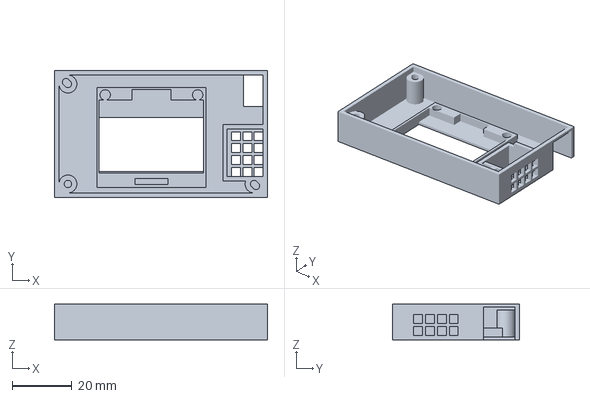
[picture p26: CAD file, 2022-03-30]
Hardware/3D files/OLED Zobrazovač/OLED Zobrazovač - Předek.3mf
71.4 x 42.5 x 12.0 mm

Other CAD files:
Hardware/3D files/Solární panely/Solární panel - Klip 1.3mf
Hardware/3D files/Štít/Štít - Krytka.3mf
Hardware/3D files/Anemometr/Anemometr - Tělo.3mf
Hardware/3D files/Držáky senzorů/Držáky senzorů - Štít.3mf
Hardware/3D files/Anemometr/Anemometr - Lopatka.3mf
Hardware/3D files/Držáky senzorů/Držáky senzorů - Anemometr.3mf
Hardware/3D files/Držáky senzorů/Držáky senzorů - Klip.3mf
Hardware/3D files/E-Ink zobrazovač/E-Ink zobrazovač - Střed.3mf
Hardware/3D files/E-Ink zobrazovač/E-Ink zobrazovač - Vrch.3mf
Hardware/3D files/Hlavní krabice/Hlavní krabice - Držák akumulátoru.3mf
Hardware/3D files/Hlavní krabice/Hlavní krabice - Držák desky.3mf
Hardware/3D files/Korouhev/Korouhev - Držák LED.3mf
Hardware/3D files/Korouhev/Korouhev - Držák.3mf
Hardware/3D files/Korouhev/Korouhev - Nos.3mf
Hardware/3D files/Korouhev/Korouhev - Rotor.3mf
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

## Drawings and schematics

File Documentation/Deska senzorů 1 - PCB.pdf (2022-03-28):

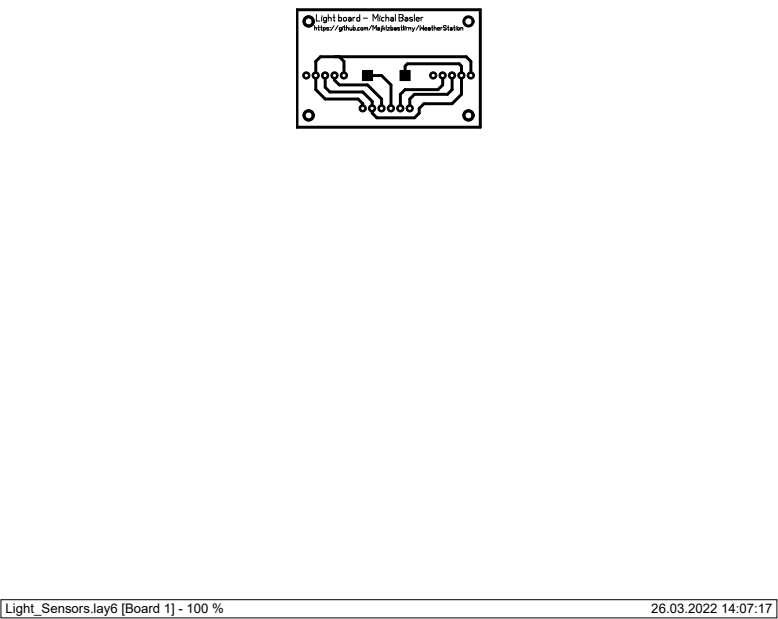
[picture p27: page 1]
Light_Sensors.lay6 [Board 1] - 100 %

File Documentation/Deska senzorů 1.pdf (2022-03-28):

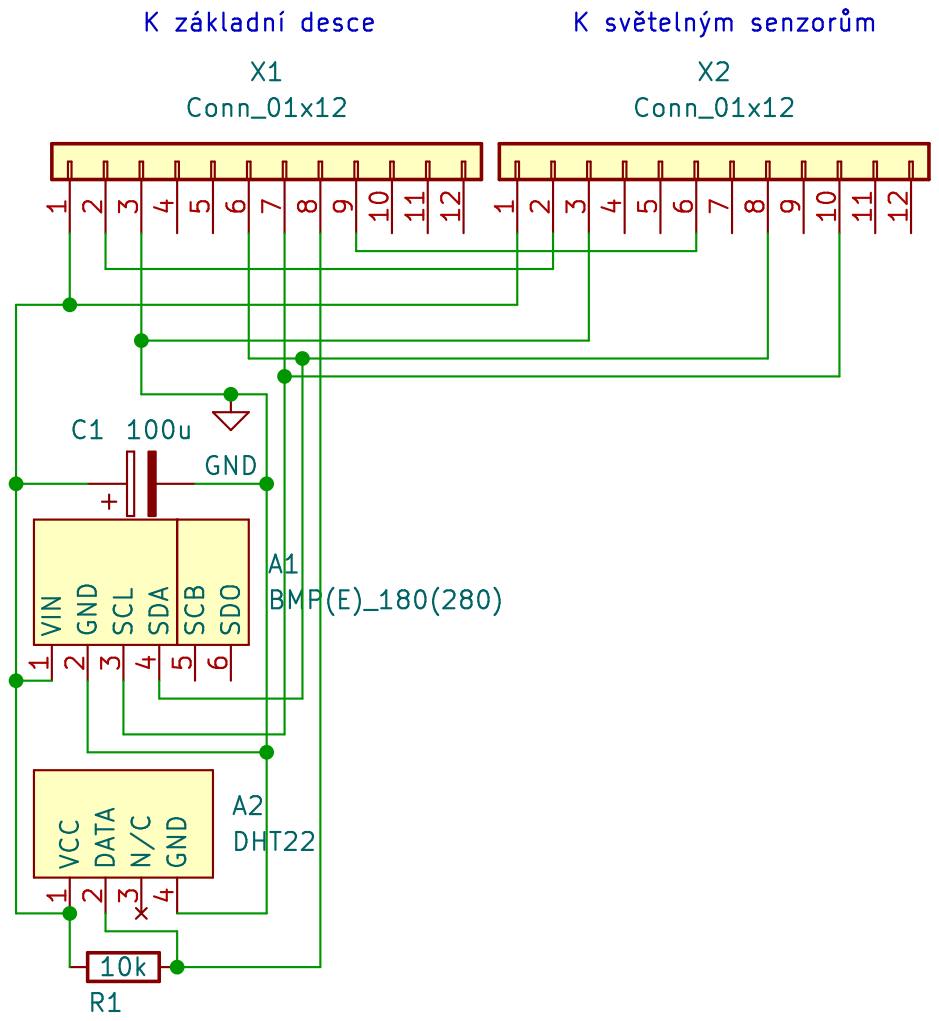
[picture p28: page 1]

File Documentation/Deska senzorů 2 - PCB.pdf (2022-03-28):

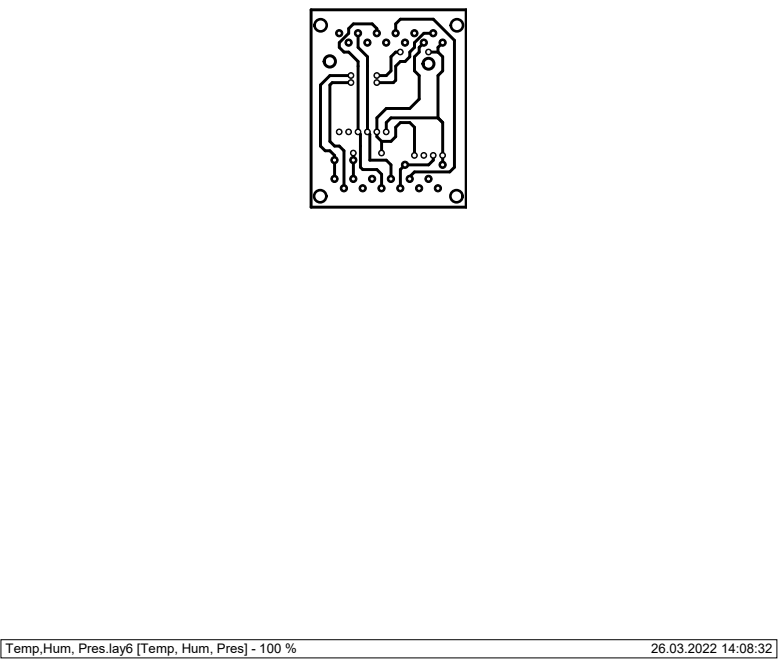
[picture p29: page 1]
Temp,Hum, Pres.lay6 [Temp, Hum, Pres] - 100 %

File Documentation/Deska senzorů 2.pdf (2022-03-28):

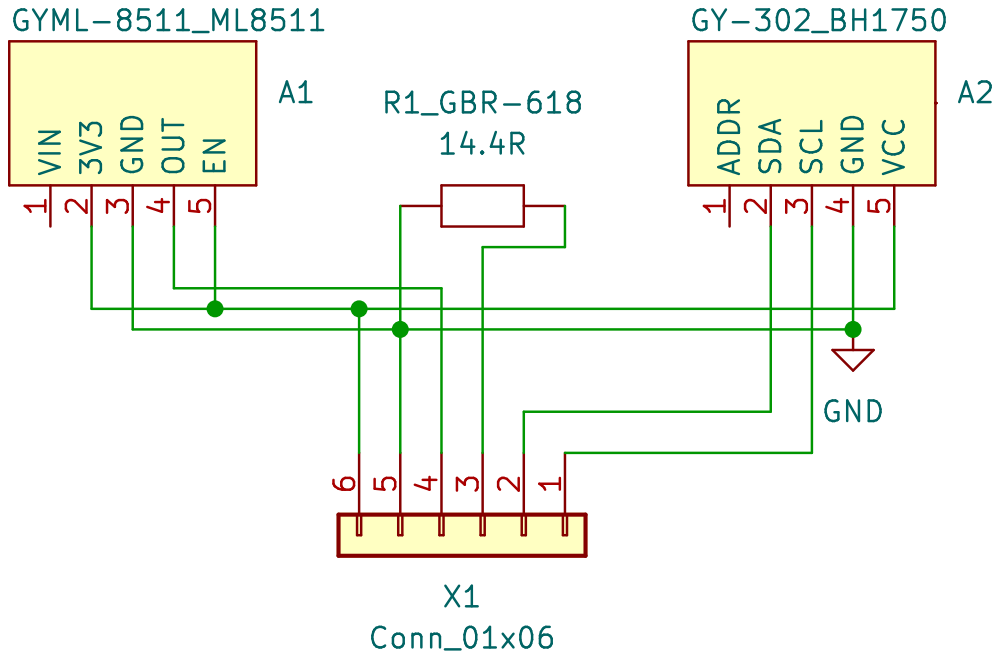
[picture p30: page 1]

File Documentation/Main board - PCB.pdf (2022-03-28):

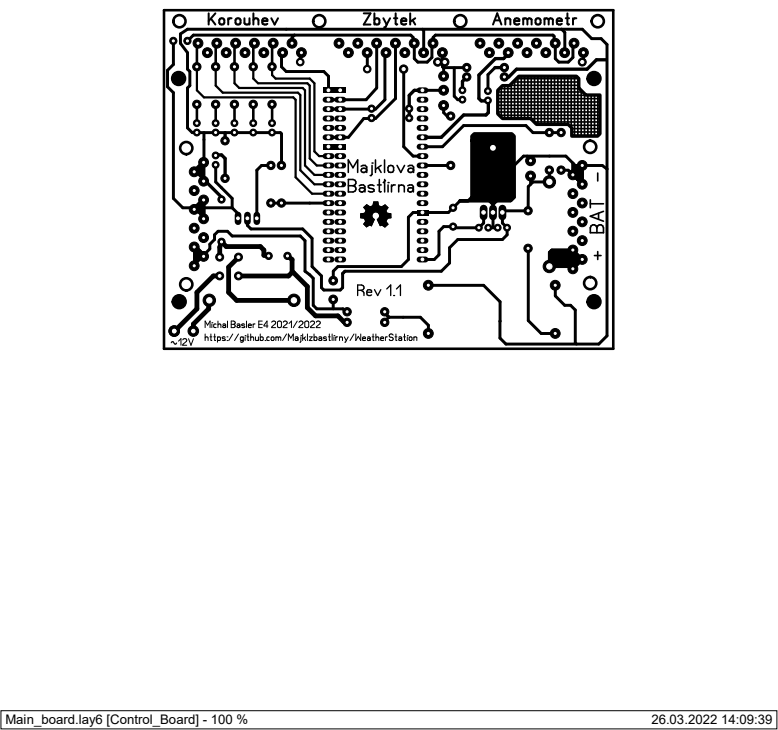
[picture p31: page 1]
Main_board.lay6 [Control_Board] - 100 %

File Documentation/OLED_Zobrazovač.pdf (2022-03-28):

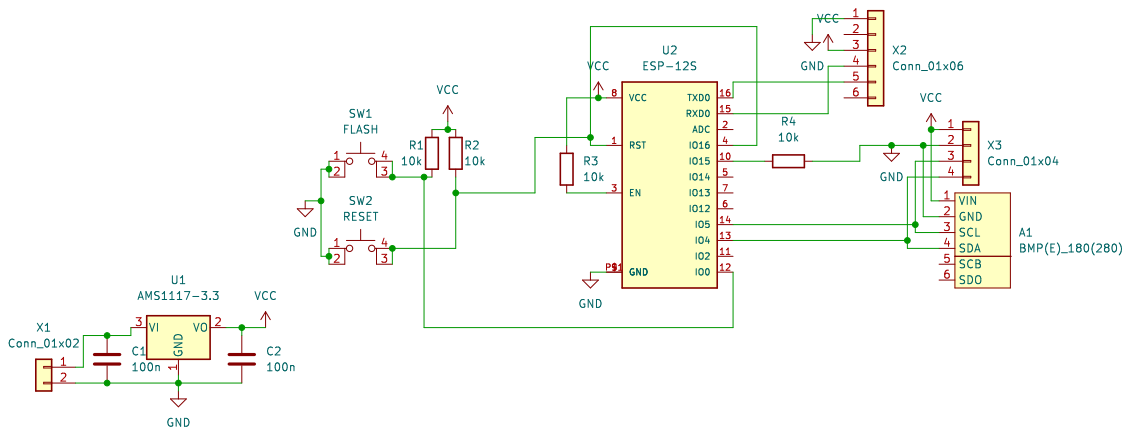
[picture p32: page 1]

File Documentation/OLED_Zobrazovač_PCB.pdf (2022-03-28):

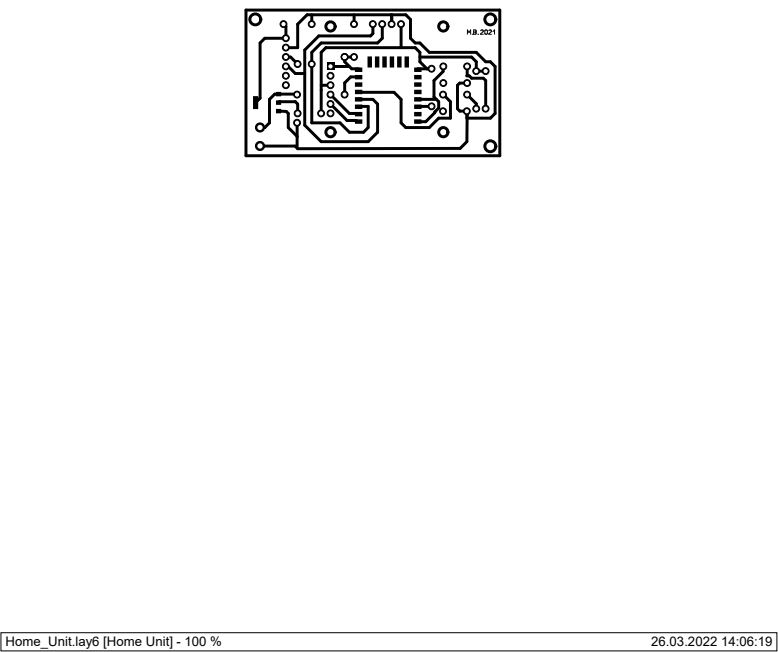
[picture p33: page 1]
Home_Unit.lay6 [Home Unit] - 100 %

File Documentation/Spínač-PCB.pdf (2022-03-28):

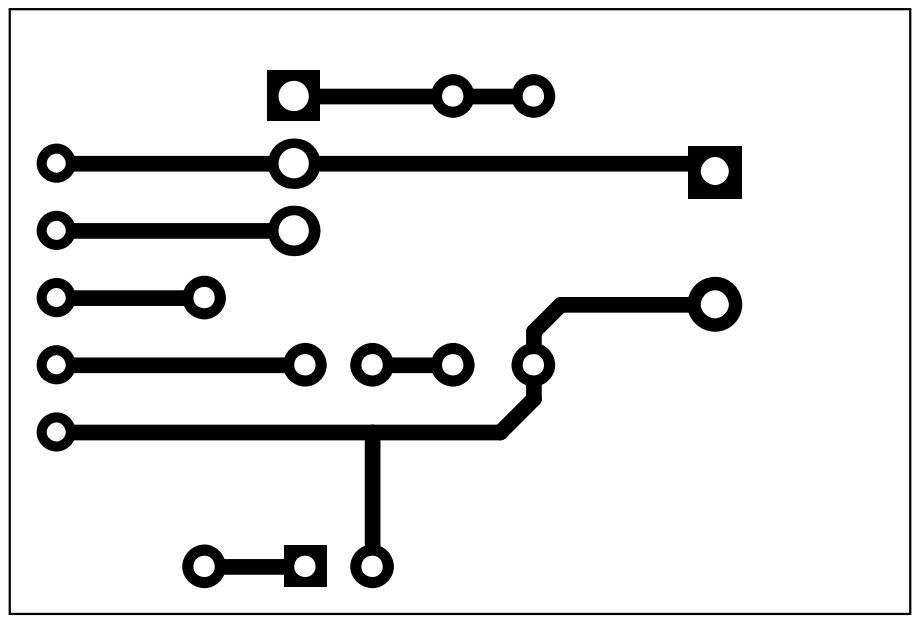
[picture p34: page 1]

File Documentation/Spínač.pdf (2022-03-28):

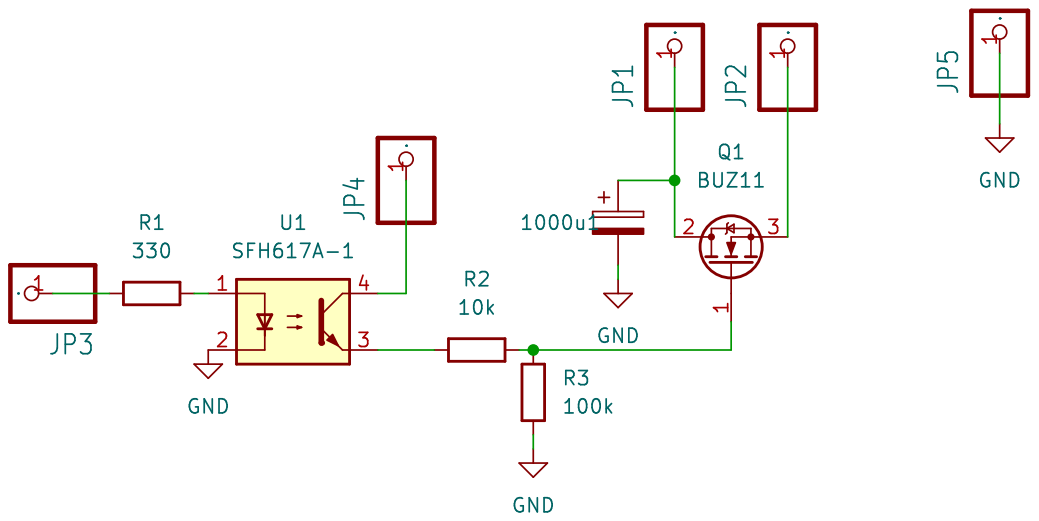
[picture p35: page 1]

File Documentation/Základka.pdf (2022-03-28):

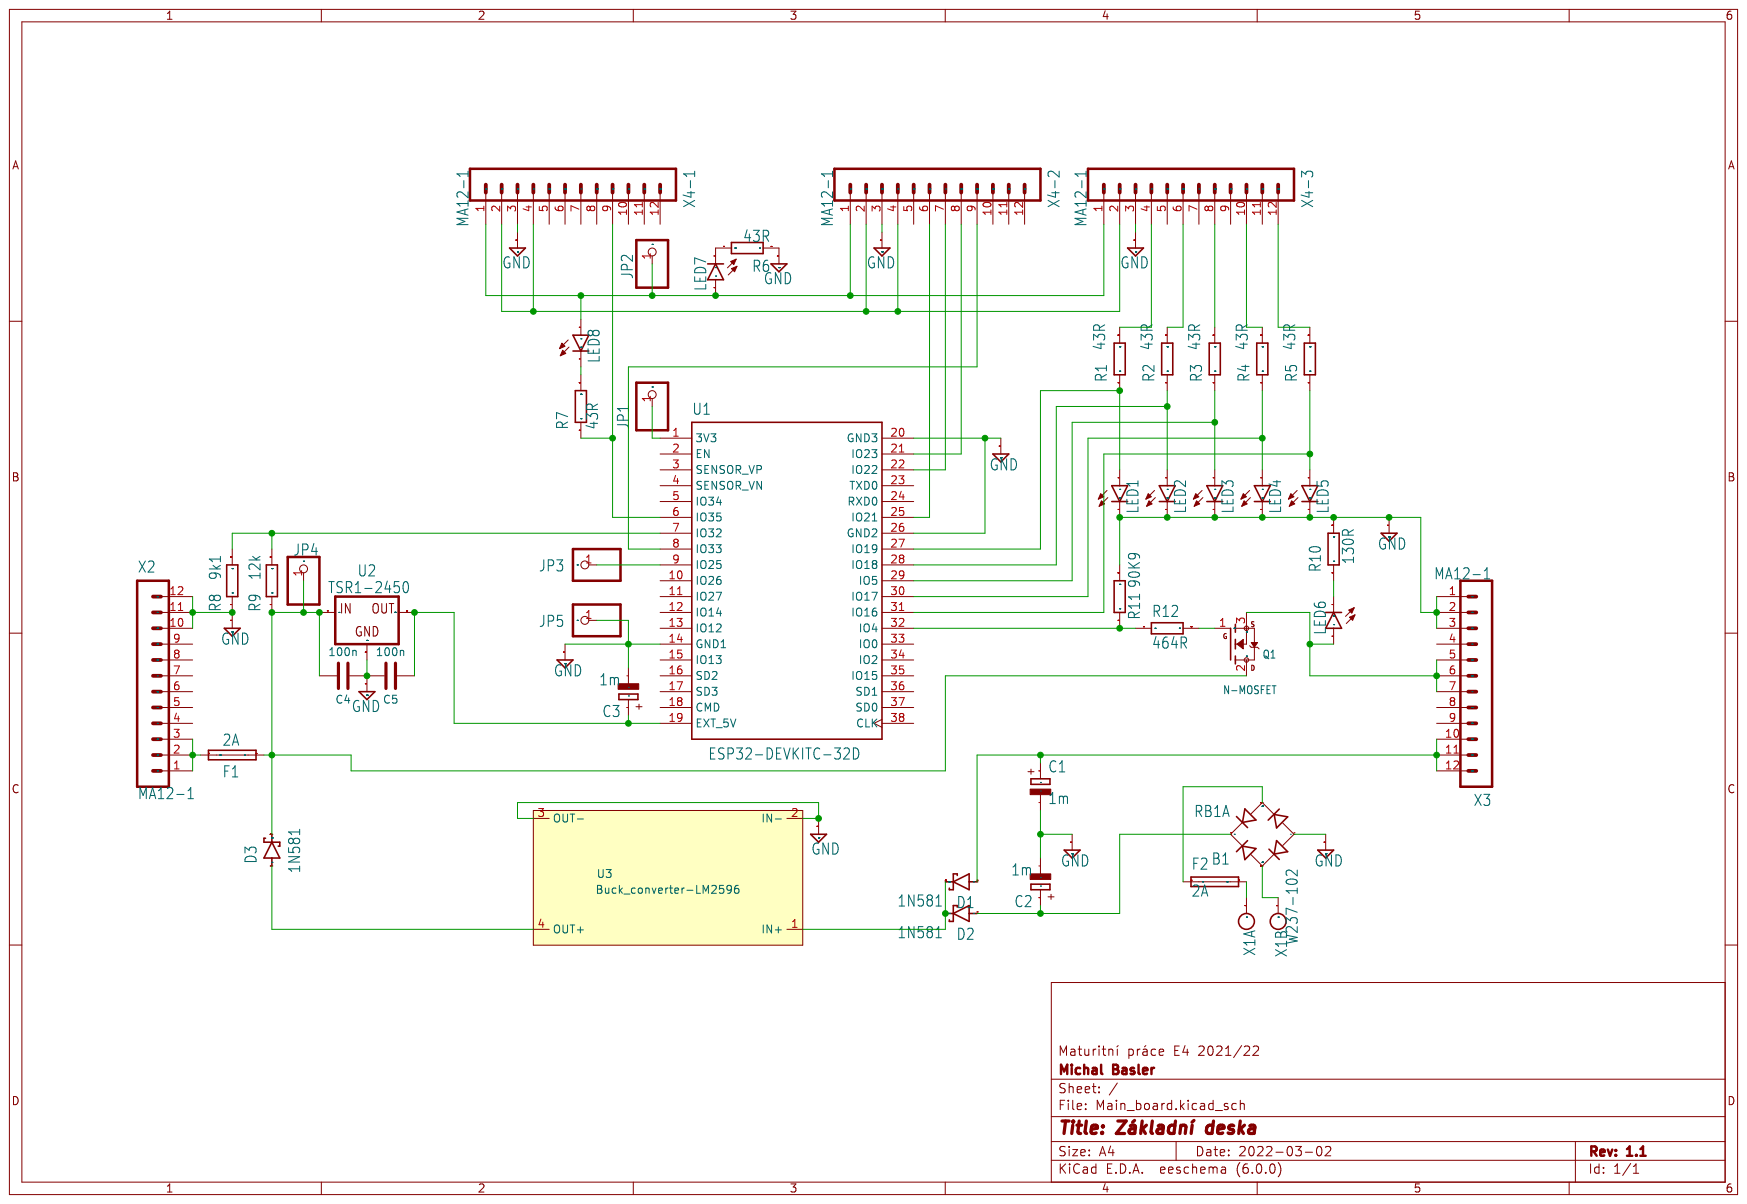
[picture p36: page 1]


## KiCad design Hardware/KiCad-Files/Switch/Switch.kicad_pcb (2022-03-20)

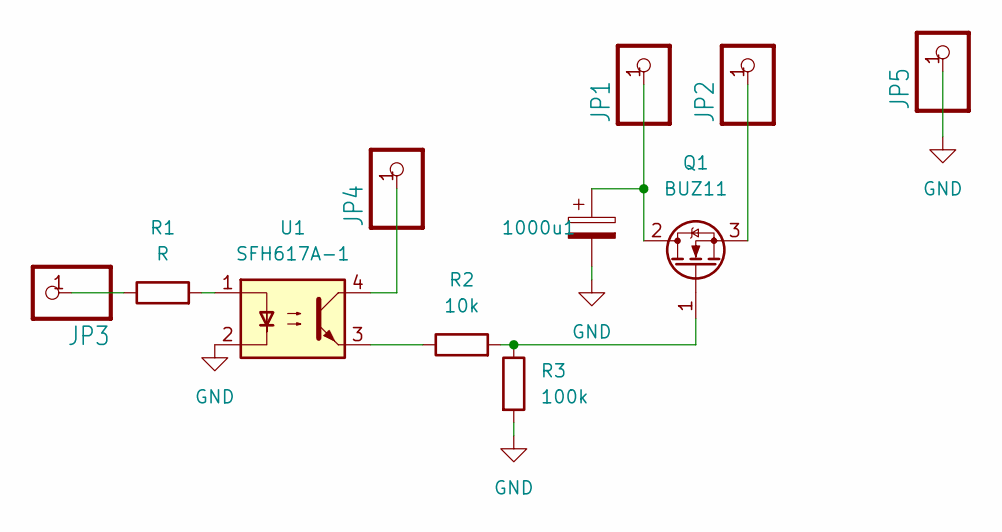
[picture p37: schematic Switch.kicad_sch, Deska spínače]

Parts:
1000u1: C_Polarized; CP_Radial_D10.0mm_P5.00mm
JP1, JP2, JP3, JP4, JP5: PINHD-1X1; Pin_D0.7mm_L6.5mm_W1.8mm_FlatFork
Q1: BUZ11; TO-220-3_Vertical
R1: R; R_Axial_DIN0207_L6.3mm_D2.5mm_P10.16mm_Horizontal
R2: 10k; R_Axial_DIN0207_L6.3mm_D2.5mm_P10.16mm_Horizontal
R3: 100k; R_Axial_DIN0207_L6.3mm_D2.5mm_P10.16mm_Horizontal
U1: SFH617A-1; DIP-4_W7.62mm

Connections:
GND: 1000u1.2, JP5.1, R3.2, U1.2
unnamed: 1000u1.1, JP1.1, Q1.2 (D)
unnamed: JP2.1, Q1.3 (S)
unnamed: JP3.1, R1.1
unnamed: JP4.1, U1.4
unnamed: Q1.1 (G), R2.2, R3.1
unnamed: R1.2, U1.1
unnamed: R2.1, U1.3

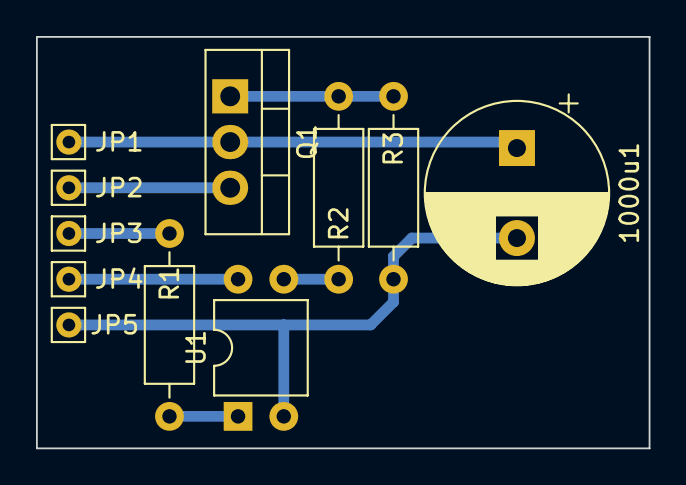
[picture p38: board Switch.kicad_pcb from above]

Board: 2 copper layers, 34.0 x 22.9 mm, 11 parts (0 on the bottom side), 8 nets.

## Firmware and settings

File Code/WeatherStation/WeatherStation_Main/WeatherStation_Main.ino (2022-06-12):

/*
  Michal Basler E4
  Hlavní kód pro meteostanici.
  Dodatky zde: https://github.com/Majklzbastlirny/WeatherStation
*/

/************************* Nutné knihovny ************************************/
#include "Adafruit_MQTT.h"
#include "Adafruit_MQTT_Client.h"
#include <WiFi.h>
#include <BH1750.h>
#include <Wire.h>
#include <Adafruit_BMP280.h>
#include <Adafruit_Sensor.h>
#include <DHT.h>
#include <DHT_U.h>

/************************* WiFi Access Point *********************************/

#define WLAN_SSID         "Edma_Venku"
#define WLAN_PASS         "pes_Fido"


/************************* MQTT Broker Setup *********************************/

#define MQTT_BROKER_IP    "192.168.0.8"
#define MQTT_BROKER_PORT  1883    //default port is 1883
#define MQTT_USERNAME     "admin"
#define MQTT_PASSWORD     "123456780"

/************ Global State (you don't need to change this!) ******************/

WiFiClient client;

Adafruit_MQTT_Client mqtt(&client, MQTT_BROKER_IP, MQTT_BROKER_PORT, MQTT_USERNAME, MQTT_PASSWORD);

/************************* MQTT Topics ***************************************/

Adafruit_MQTT_Publish temperature = Adafruit_MQTT_Publish(&mqtt, "WeatherStation/Temperature");
Adafruit_MQTT_Publish temperature2 = Adafruit_MQTT_Publish(&mqtt, "WeatherStation/Temperature2");
Adafruit_MQTT_Publish humidity = Adafruit_MQTT_Publish(&mqtt, "WeatherStation/Humidity");
Adafruit_MQTT_Publish light = Adafruit_MQTT_Publish(&mqtt, "WeatherStation/Light");
Adafruit_MQTT_Publish presss = Adafruit_MQTT_Publish(&mqtt, "WeatherStation/Pressure");
Adafruit_MQTT_Publish pressraw = Adafruit_MQTT_Publish(&mqtt, "WeatherStation/PressureRAW");
Adafruit_MQTT_Publish UV = Adafruit_MQTT_Publish(&mqtt, "WeatherStation/UV");
Adafruit_MQTT_Publish WV = Adafruit_MQTT_Publish(&mqtt, "WeatherStation/WindDir");
Adafruit_MQTT_Publish WS = Adafruit_MQTT_Publish(&mqtt, "WeatherStation/Speed");
Adafruit_MQTT_Publish BatVoltage = Adafruit_MQTT_Publish(&mqtt, "WeatherStation/Voltage");
Adafruit_MQTT_Publish Heater = Adafruit_MQTT_Publish(&mqtt, "WeatherStation/HeaterStatus");
Adafruit_MQTT_Publish Dew = Adafruit_MQTT_Publish(&mqtt, "WeatherStation/DewPoint");
Adafruit_MQTT_Publish HInd = Adafruit_MQTT_Publish(&mqtt, "WeatherStation/HIndex");
Adafruit_MQTT_Publish WChill = Adafruit_MQTT_Publish(&mqtt, "WeatherStation/WChill");
Adafruit_MQTT_Publish Precipitation = Adafruit_MQTT_Publish(&mqtt, "WeatherStation/Precipitation");


/******************* Globální proměnné, definice a objekty **************************************/
//Seriový výstup zapnut
#define Sprintln(a) (Serial.println(a))
#define Sprint(a) (Serial.print(a))

//Seriový výstup vypnut
//#define Sprintln(a)
//#define Sprint(a)


#define DOBA_HIBERNACE 120 //v sekundách
#define mezera 10000 //mezera mezi měřením (v ms)
#define LEDDIAG 2
int rescnt = 0;


//Proměnné ke korouhvi
bool D1 = 0;
bool D2 = 0;
bool D3 = 0;
bool D4 = 0;
bool D5 = 0;
float wv = 0;

//Proměnné k anemometru
float ws = 0; //V M/S
float wsm = 0;
#define AnemoPIN  35

float AnemoTime = 10; //doba měření rychlosti v s
byte pulses = 0;

//Proměnné k senzoru intenzity UV zařízení
int UVOUT = 33;
int REF_3V3 = 34;
uint32_t x = 0;
int uvLevel = 0;
int refLevel = 0;
float uvIntensity = 0;
float outputVoltage = 0;

//Proměnné k senzoru vlhkosti a teploty DHT22
float hd = 0;
float td = 0;
#define DHTPIN 23 //4
#define DHTTYPE DHT22
DHT dht(DHTPIN, DHTTYPE);
double DewPoint = 0;
double HeatIndex = 0;
double WindChill = 0;



//Proměnné k senzoru světla BH1750
float lux = 0;
BH1750 lightMeter;

//Proměnné k senzoru teploty a tlaku BMP280
Adafruit_BMP280 bmp;
#define NadmVys 333
double Tf = 0;
double T, P, p0;

//Proměnné k vyhřívacímu systému
RTC_DATA_ATTR bool HeatOn = 0;
int MinTemp = -5;
#define HeatPin 4
RTC_DATA_ATTR bool Heatin = 0;

//Proměnné k senzoru napětí
#define voltmeas 32
float voltage = 0;

//Proměnné k odpojovači senzorů
#define SensorPWR 25
short wificount = 0;

float precipitation = 0;





/*************************** Vlastní kód ************************************/



void setup() {
  // Wire.setClock(5000);
  Wire.begin(21, 22);
  Serial.begin(115200);

  /******** Nastavení pinů ***********/
  pinMode(LEDDIAG, OUTPUT);
  pinMode(SensorPWR, OUTPUT);
  digitalWrite(SensorPWR, HIGH);

  //Nastavení pinů pro UV senzor
  pinMode(UVOUT, INPUT);
  pinMode(REF_3V3, INPUT);

  //Nastavení pinů směrovky větru
  pinMode(19, INPUT_PULLDOWN);
  pinMode(18, INPUT_PULLDOWN);
  pinMode(5, INPUT_PULLDOWN);
  pinMode(17, INPUT_PULLDOWN);
  pinMode(16, INPUT_PULLDOWN);

  D5 = digitalRead(19);
  D4 = digitalRead(18);
  D3 = digitalRead(5);
  D2 = digitalRead(17);
  D1 = digitalRead(16);

  pinMode(AnemoPIN, INPUT);
  pinMode(HeatPin, OUTPUT);
  if (Heatin == 1) {
    digitalWrite(HeatPin, HIGH);
  }
  else {}

  digitalWrite(HeatPin, LOW);
  digitalWrite(SensorPWR, HIGH);
  delay(2000);
  unsigned status;
  status = bmp.begin(0x76, 0x58);

  dht.begin();
  delay(250);

}


void loop() {
  digitalWrite(SensorPWR, HIGH);
  digitalWrite(LEDDIAG, LOW);
  delay(2000);
  Sprintln("");
  ReadLight();
  ReadBattery();
  ReadBMP();
  MeasureUV();
  ReadAngle();
  ReadSpeed();
  ReadDHT();

  digitalWrite(SensorPWR, LOW);
  WiFi_Connect();
  MQTT_Connect();
  PublishMQTT();
  WiFi_Disconnect();

  rescnt++;
  if (rescnt == 1) {
    Hibernace();
  } else {
    Sprint("Počet provedených měření od restartu: ");
    Sprintln(rescnt);
  }
  delay(mezera);
  digitalWrite(LEDDIAG, HIGH );
  delay(100);
}



/****************************Všechny zbytky kódů**********************************/


//kód pro čtení intenzity osvětlení ze senzoru BH1750
void ReadLight() {
  lightMeter.begin();
  delay(200);
  lux = lightMeter.readLightLevel();

  Sprint("Světelnost: ");
  Sprint(lux);
  Sprintln(" lux");
}

//Kód pro měření napětí na baterii
void ReadBattery() {
  voltage = (((analogRead(voltmeas) * 8.158) / 4095) + 0.13);
  Sprint("Napětí na baterce: ");
  Sprint(voltage);
  Sprintln(" V");
  delay(10);
}

//Kód pro čtení tlaku a teploty ze senzoru BMP280
void ReadBMP() {
  Sprint("Nadmořská výška stanice: ");
  Sprint(NadmVys);
  Sprintln(" m.n.m.");

  Sprint(F("Teplota: "));
  T = bmp.readTemperature();
  Sprint(T);
  Sprint(" *C = ");
  Tf = ((T * 1.8) + 32);
  Sprint(Tf);
  Sprintln(" °F");

  Sprint(F("Absolutní tlak: "));
  P = (bmp.readPressure() / 100);
  Sprint(P);
  Sprintln(" hPa");

  Sprint(F("Relativní tlak: "));
  delay(5);
  p0 = (((bmp.readPressure()) / pow((1 - ((float)(NadmVys)) / 44330), 5.255)) / 100.0);
  Sprint(p0);
  Sprintln(" hPa");

  delay(1);

  if (T < MinTemp) {
    digitalWrite(HeatPin, 1);
    Heatin = 1;
  }
  else if (T >= MinTemp) {
    digitalWrite(HeatPin, 0);
    Heatin = 0;
  }
  else {}
}

//Kód pro měření UV intenzity senzorem ML8511
void MeasureUV() {
  uvLevel = averageAnalogRead(UVOUT);
  refLevel = averageAnalogRead(REF_3V3);

  //Use the 3.3V power pin as a reference to get a very accurate output value from sensor
  outputVoltage = 3.3 / 4095 * uvLevel;   // adjust outputVoltage to actual voltage in case you read negative values.

  uvIntensity = mapfloat(outputVoltage, 0.99, 2.8, 0.0, 15.0); //Convert the voltage to a UV intensity level
  if (uvIntensity < 0) {
    uvIntensity = 0;
  }
  else {
    uvIntensity = uvIntensity;
  }

  Sprint("UV intenzita (mW/cm^2): ");
  Sprint(uvIntensity);
  Sprintln("");
}

//Kód pro překlad jednocestného Grayova kódu na úhel
void ReadAngle() {
  if (D1 ==  1 && D2 == 0  && D3 == 0 && D4 == 0 && D5 == 0 ) {
    wv = 0;
  }
  else if (D1 ==  1 && D2 == 1  && D3 == 0 && D4 == 0 && D5 == 0 ) {
    wv = 12;
  }
  else if (D1 ==  1 && D2 == 1  && D3 == 0 && D4 == 1 && D5 == 0 ) {
    wv = 24;
  }
  else if (D1 ==  1 && D2 == 1  && D3 == 0 && D4 == 1 && D5 == 1 ) {
    wv = 36;
  }
  else if (D1 ==  1 && D2 == 1  && D3 == 0 && D4 == 0 && D5 == 1 ) {
    wv = 48;
  }
  else if (D1 ==  0 && D2 == 1  && D3 == 0 && D4 == 0 && D5 == 1 ) {
    wv = 60;
  }
  else if (D1 ==  0 && D2 == 1  && D3 == 0 && D4 == 0 && D5 == 0 ) {
    wv = 72;
  }
  else if (D1 ==  0 && D2 == 1  && D3 == 1 && D4 == 0 && D5 == 0 ) {
    wv = 84;
  }
  else if (D1 ==  0 && D2 == 1  && D3 == 1 && D4 == 0 && D5 == 1 ) {
    wv = 96;
  }
  else if (D1 ==  1 && D2 == 1  && D3 == 1 && D4 == 0 && D5 == 1 ) {
    wv = 108;
  }
  else if (D1 ==  1 && D2 == 1  && D3 == 1 && D4 == 0 && D5 == 0 ) {
    wv = 120;
  }
  else if (D1 ==  1 && D2 == 0  && D3 == 1 && D4 == 0 && D5 == 0 ) {
    wv = 132;
  }
  else if (D1 ==  0 && D2 == 0  && D3 == 1 && D4 == 0 && D5 == 0 ) {
    wv = 144;
  }
  else if (D1 ==  0 && D2 == 0  && D3 == 1 && D4 == 1 && D5 == 0 ) {
    wv = 156;
  }
  else if (D1 ==  1 && D2 == 0  && D3 == 1 && D4 == 1 && D5 == 0 ) {
    wv = 168;
  }
  else if (D1 ==  1 && D2 == 1  && D3 == 1 && D4 == 1 && D5 == 0 ) {
    wv = 180;
  }
  else if (D1 ==  0 && D2 == 1  && D3 == 1 && D4 == 1 && D5 == 0 ) {
    wv = 192;
  }
  else if (D1 ==  0 && D2 == 1  && D3 == 0 && D4 == 1 && D5 == 0 ) {
    wv = 204;
  }
  else if (D1 ==  0 && D2 == 0  && D3 == 0 && D4 == 1 && D5 == 0 ) {
    wv = 216;
  }
  else if (D1 ==  0 && D2 == 0  && D3 == 0 && D4 == 1 && D5 == 1 ) {
    wv = 228;
  }
  else if (D1 ==  0 && D2 == 1  && D3 == 0 && D4 == 1 && D5 == 1 ) {
    wv = 240;
  }
  else if (D1 ==  0 && D2 == 1  && D3 == 1 && D4 == 1 && D5 == 1 ) {
    wv = 252;
  }
  else if (D1 ==  0 && D2 == 0  && D3 == 1 && D4 == 1 && D5 == 1 ) {
    wv = 264;
  }
  else if (D1 ==  0 && D2 == 0  && D3 == 1 && D4 == 0 && D5 == 1 ) {
    wv = 276;
  }
  else if (D1 ==  0 && D2 == 0  && D3 == 0 && D4 == 0 && D5 == 1 ) {
    wv = 288;
  }
  else if (D1 ==  1 && D2 == 0  && D3 == 0 && D4 == 0 && D5 == 1 ) {
    wv = 300;
  }
  else if (D1 ==  1 && D2 == 0  && D3 == 1 && D4 == 0 && D5 == 1 ) {
    wv = 312;
  }
  else if (D1 ==  1 && D2 == 0  && D3 == 1 && D4 == 1 && D5 == 1 ) {
    wv = 324;
  }
  else if (D1 ==  1 && D2 == 0  && D3 == 0 && D4 == 1 && D5 == 1 ) {
    wv = 336;
  }
  else if (D1 ==  1 && D2 == 0  && D3 == 0 && D4 == 1 && D5 == 0 ) {
    wv = 348;
  }
  else {
    wv = 0;
  }

  Sprint("Směr větru je: ");
  Sprint(wv);
  Sprint("°   ");
  //Sprintln(D1, D2, D3, D4, D5);
  Sprint(D5);
  Sprint(" ");
  Sprint(D4);
  Sprint(" ");
  Sprint(D3);
  Sprint(" ");
  Sprint(D2);
  Sprint(" ");
  Sprint(D1);
  Sprintln("");
}

//Kód pro čtení teploty a vlhkosti ze senzoru DHT22
void ReadDHT() {

  td = (dht.readTemperature());
  hd = dht.readHumidity();
  delay(100);

  if (isnan(hd) || isnan(td)) {
    Sprintln(F("Failed to read from DHT sensor!"));
  }
  else {

  }

  Sprint(F("Vlhkost: "));
  Sprint(hd);
  Sprintln("%");
  Sprint(F("Teplota DHT22: "));
  Sprint(td);
  Sprintln(F(" °C "));


  DewPoint = (T - (100 - hd) / 5.883);

  Sprint(F("Rosný bod je "));
  Sprint(DewPoint);
  Sprintln("°C");
  if ((T < 10) && (wsm > 4.8)) {
    WindChill = (13.12 + 0.6215 * T - 11.37 * pow(wsm, 0.16) + 0.3965 * T * pow(wsm, 0.16));
  }
  else {
    WindChill = T;
  }

  Sprint(F("Větrný chlad je: "));
  Sprint(WindChill);
  Sprintln("°C");


  HeatIndex = dht.computeHeatIndex(T, hd, false);
  Sprint(F("Pocitová teplota je: "));
  Sprint(HeatIndex);
  Sprintln("°C");

}

//Kód pro měření rychlosti větru
void ReadSpeed() {
  attachInterrupt(AnemoPIN, ISR, FALLING);
  delay(AnemoTime*1000);
  detachInterrupt(AnemoPIN);
  ws = ((pulses/4)/AnemoTime); //obvod je 50cm, 4 imp = 1m/s
  Sprint("Rychlost větru: ");
  Sprint(ws);
  Sprint(" m/s = ");
  wsm = ws * 3.6;
  Sprint(wsm);
  Sprintln(" km/h");
}

void ISR() {
  pulses++;
}

//Kód pro připojení k WiFi síti
void WiFi_Connect() {
  Sprint("Připojuji se k: ");
  Sprintln(WLAN_SSID);
  WiFi.begin(WLAN_SSID, WLAN_PASS);
  while (WiFi.status() != WL_CONNECTED) {
    delay(400);
    Sprint(".");
    wificount++;
    delay(100);
    if (wificount < 40) {

    }
    else {
      digitalWrite(SensorPWR, LOW);
      digitalWrite(HeatPin, LOW);

      ESP.restart();
    }
  }
  Sprintln("Uspěšně připojeno");
  Sprint("Moje IP adresa: ");
  Sprintln(WiFi.localIP());
  long rssi = WiFi.RSSI();
  Sprint("Síla WiFi signálu je: ");
  Sprint(rssi);
  Sprintln(" dBm");
}

//Kód pro připojení k MQTT serveru
void MQTT_Connect() {
  int8_t ret;
  digitalWrite(LEDDIAG, HIGH );

  // Stop if already connected.
  if (mqtt.connected()) {
    return;
  }

  Sprintln("Připojuji se k MQTT serveru ");

  uint8_t retries = 4;
  mqtt.connect();
  while ((ret = mqtt.connect()) != 0) { // connect will return 0 for connected
    Sprintln(mqtt.connectErrorString(ret));
    Sprintln("Nepodařilo se mi připojit k MQTT serveru. Zkusím to znovu za 5 sekund.");
    mqtt.disconnect();
    delay(5000);  // wait 5 seconds
    retries--;
    if (retries == 0) {
      // basically die and wait for user to reset me
      digitalWrite(SensorPWR, LOW);
      digitalWrite(HeatPin, LOW);

      ESP.restart();
    }
  }
  Sprintln("Úspěšně připojeno k MQTT serveru!");
}

//Kód pro odeslání dat na MQTT server
void PublishMQTT() {

  Sprintln(F("Probíhá odesílání dat na server"));
  Sprint(F("Probíhá odesílání teploty:"));
  if (! temperature.publish(T)) {
    Sprintln(F(" Failed"));
  } else {
    Sprintln(F(" OK!"));
  }
  delay(150);

  Sprint(F("Probíhá odesílání teploty (záloha):"));
  if (! temperature2.publish(td)) {
    Sprintln(F(" Failed"));
  } else {
    Sprintln(F(" OK!"));
  }
  delay(150);

  Sprint(F("Probíhá odesílání vlhkosti:"));
  if (! humidity.publish(hd)) {
    Sprintln(F(" Failed"));
  } else {
    Sprintln(F(" OK!"));
  }
  delay(150);

  Sprint(F("Probíhá odesílání světelnosti:"));
  if (! light.publish(lux)) {
    Sprintln(F(" Failed"));
  } else {
    Sprintln(F(" OK!"));
  }
  delay(150);

  if (P != 0) {

    Sprint(F("Probíhá odesílání tlaku:"));
    if (! presss.publish(p0)) {
      Sprintln(F(" Failed"));
    } else {
      Sprintln(F(" OK!"));
    }
    delay(150);

    Sprint(F("Probíhá odesílání tlaku (RAW):"));
    if (! pressraw.publish(P)) {
      Sprintln(F(" Failed"));
    } else {
      Sprintln(F(" OK!"));
    }
    delay(150);
  }
  else {}

  Sprint(F("Probíhá odesílání UV intenzity:"));
  if (! UV.publish(uvIntensity)) {
    Sprintln(F(" Failed"));
  } else {
    Sprintln(F(" OK!"));
  }
  delay(150);

  Sprint(F("Probíhá odesílání směru větru:"));
  if (! WV.publish(wv)) {
    Sprintln(F(" Failed"));
  } else {
    Sprintln(F(" OK!"));
  }
  delay(150);

  Sprint(F("Probíhá odesílání rychlosti větru:"));
  if (! WS.publish(ws)) {
    Sprintln(F(" Failed"));
  } else {
    Sprintln(F(" OK!"));
  }
  delay(150);

  Sprint(F("Probíhá odesílání napětí baterie:"));
  if (! BatVoltage.publish(voltage)) {
    Sprintln(F(" Failed"));
  } else {
    Sprintln(F(" OK!"));
  }
  delay(150);

  Sprint(F("Probíhá odesílání stavu vytápění:"));
  if (! Heater.publish(Heatin)) {
    Sprintln(F(" Failed"));
  } else {
    Sprintln(F(" OK!"));
  }
  delay(150);

  Sprint(F("Probíhá odesílání rosného bodu:"));
  if (! Dew.publish(DewPoint)) {
    Sprintln(F(" Failed"));
  } else {
    Sprintln(F(" OK!"));
  }
  delay(150);

  Sprint(F("Probíhá odesílání pocitové teploty:"));
  if (! HInd.publish(HeatIndex)) {
    Sprintln(F(" Failed"));
  } else {
    Sprintln(F(" OK!"));
  }
  delay(150);

  Sprint(F("Probíhá odesílání větrného chladu:"));
  if (! WChill.publish(WindChill)) {
    Sprintln(F(" Failed"));
  } else {
    Sprintln(F(" OK!"));
  }
  delay(150);

  Sprint(F("Probíhá odesílání srážek:"));
  if (! Precipitation.publish(precipitation)) {
    Sprintln(F(" Failed"));
  } else {
    Sprintln(F(" OK!"));
  }
  delay(150);
}

//Kód pro odpojení od WiFi sítě
void WiFi_Disconnect() {
  WiFi.disconnect(true);  // Disconnect from the network
  WiFi.mode(WIFI_OFF);    // Switch WiFi off
  digitalWrite(LEDDIAG, LOW);
}

//Kód pro přechodu mikrokontroleru do režimu hibernace
void Hibernace() {
  digitalWrite(SensorPWR, LOW);
  digitalWrite(HeatPin, LOW);

  Sprintln("Jdu do režimu hibernace");
  esp_sleep_enable_timer_wakeup(DOBA_HIBERNACE * 1000000);
  esp_deep_sleep_start();
}


//Dodatečný kód pro čtení UV intenzity
int averageAnalogRead( int pinToRead)
{
  byte numberOfReadings = 8;
  int runningValue = 0;

  for (int x = 0 ; x < numberOfReadings ; x++)
    runningValue += analogRead(pinToRead);
  runningValue /= numberOfReadings;

  return (runningValue);
}

float mapfloat(float x, float in_min, float in_max, float out_min, float out_max)
{
  return (x - in_min) * (out_max - out_min) / (in_max - in_min) + out_min;

}

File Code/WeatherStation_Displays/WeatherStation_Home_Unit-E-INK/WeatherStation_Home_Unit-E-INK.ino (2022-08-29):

#include <WiFi.h>
#include <ESP32Ping.h>
#include <Arduino.h>
#include <esp_task_wdt.h>
#include "freertos/FreeRTOS.h"
#include "freertos/task.h"
#include "epd_driver.h"

#include "firasans.h"
#include "opensans10b.h"
#include "opensans24b.h"
#include "MAX.h"
#include "MAX2.h"

#include "esp_adc_cal.h"
#include <Wire.h>

#include <InfluxDbClient.h>
#include <InfluxDbCloud.h>
//#include "efontEnableAll.h"

#include <Adafruit_BME280.h>
#include <Adafruit_Sensor.h>
#include <DHT.h>
#include <DHT_U.h>
DHT dht(0, DHT22);


double HeatIndex = 0;


#define I2C_SDA 14
#define I2C_SCL 15
#define DOBA_HIBERNACE 120 //v sekundách
//#define FAILsleep 30 //v minutách
RTC_DATA_ATTR byte FAILcount = 0;
RTC_DATA_ATTR byte FAILdata = 0;
RTC_DATA_ATTR char failsleep[64];
RTC_DATA_ATTR long FAILsleeptimer = 0;
byte FAILsleep = 30;  //Čas spánku v minutách


//#define INFLUXDB_URL "http://192.168.0.8:8086"
//#define INFLUXDB_URL "http://bladyhel.serveminecraft.net:8086"
String INFLUXDB_URL = "http://bladyhel.serveminecraft.net:8086";
#define INFLUXDB_TOKEN "H4hYgXBEUTFRivBBLdo0Pk_ca1qCAmN8O-LRGjRLRoVitVGcSfervwQQOKa8Jka7rwDa2m7EDlqZn_MmNqsezQ=="
#define INFLUXDB_ORG "2d5652347a7565e5"
#define INFLUXDB_BUCKET "WeatherStation"
String query = "from(bucket: \"" INFLUXDB_BUCKET "\") |> range(start: -1h) |> last() ";


// Set timezone string according to https://www.gnu.org/software/libc/manual/html_node/TZ-Variable.html
#define TZ_INFO "CET-1CEST,M3.5.0,M10.5.0/3"

// InfluxDB client instance with preconfigured InfluxCloud certificate
InfluxDBClient client(INFLUXDB_URL, INFLUXDB_ORG, INFLUXDB_BUCKET, INFLUXDB_TOKEN, InfluxDbCloud2CACert);

double dewpoint = 0;
char DEWPOINT[64];
double heatindex = 0;
char HEATINDEX[64];
bool heaterstatus = 0;
char HEATERSTATUS[64];
double humidity = 0;
char HUMIDITY[64];
double light = 0;
char LIGHT[64];
double precipitation = 0;
char PRECIPITATION[64];
double pressure = 0;
char PRESSURE[64];
double pressureraw = 0;
char PRESSURERAW[64];
double wspeed = 0;
char WSPEED[64];
double temperature = 0;
char TEMPERATURE[64];
double temperature2 = 0;
char TEMPERATURE2[64];
double uv = 0;
char UV[64];
double voltage = 0;
char VOLTAGE[64];
byte winddir = 0;
char WINDDIR[64];
double windchill = 0;
char WINDCHILL[64];

char* winddirection = 0;

short Year = 0;
short Month = 0;
short Day = 0;
short WeekDay = 0;
short Hour = 0;
short Minute = 0;
short Second = 0;
char Seconds[16];
char Minutes[16];
char Hours[16];
char buffertime[32];
char bufferdate[32];

const char *ssid     = "MediumRecords";
const char *password = "123456780";
short wificount = 0;

char daysOfTheWeek[7][12] = {"Nedele", "Pondeli", "Utery", "Streda", "Ctvrtek", "Patek", "Sobota"};
char months[12][12] = {"Prosinec", "Leden", "Unor", "Brezen", "Duben", "Kveten", "Cerven", "Cervenec", "Srpen", "Zari", "Rijen", "Listopad"};

int cursor_x = 0;
int cursor_y = 0;




TwoWire I2CBME = TwoWire(0);

Adafruit_BME280 bme;

#define BATT_PIN            36
#define SD_MISO             12
#define SD_MOSI             13
#define SD_SCLK             14
#define SD_CS               15

uint8_t *framebuffer;
int vref = 1100;

Rect_t area1 = {
  .x = 585,
  .y = 60,
  .width = 290,
  .height = 60
};
Rect_t ConnectArea = {
  .x = 225,
  .y = 0,
  .width = 360,
  .height = 60
};



void setup()
{
  Serial.begin(115200);
  Serial.println(FAILdata);
  Serial.println(FAILsleeptimer);
  epd_init();
  DisplayTime();
  DisplayTimeDate();
  // Correct the ADC reference voltage

  if (FAILdata = 1 & FAILsleeptimer > 1) {
    epd_clear_area_cycles(ConnectArea, 3, 250);

    cursor_x = 230;
    cursor_y = 20;
    writeln((GFXfont *)&OpenSans10B, "Nepodarilo se pripojit.", &cursor_x, &cursor_y, NULL);
    cursor_x = 230;
    cursor_y = 40;

    dtostrf(FAILsleeptimer, 6, 0, failsleep);
    writeln((GFXfont *)&OpenSans10B, "Za", &cursor_x, &cursor_y, NULL);
    writeln((GFXfont *)&OpenSans10B, failsleep, &cursor_x, &cursor_y, NULL);
    writeln((GFXfont *)&OpenSans10B, " minut zkusim znovu", &cursor_x, &cursor_y, NULL);
    FAILsleeptimer -= 5;
    esp_sleep_enable_timer_wakeup(5 * 1000000 * 60);
    epd_poweroff_all();
    esp_deep_sleep_start();
  }
  else {
  }

  if (FAILdata = 1 & FAILsleeptimer <= 1) {
    FAILdata = 0;

  }
  else {

  }


  uint8_t percentage = 100;
  esp_adc_cal_characteristics_t adc_chars;
  esp_adc_cal_value_t val_type = esp_adc_cal_characterize(ADC_UNIT_1, ADC_ATTEN_DB_11, ADC_WIDTH_BIT_12, 1100, &adc_chars);
  if (val_type == ESP_ADC_CAL_VAL_EFUSE_VREF) {
    Serial.printf("eFuse Vref:%u mV", adc_chars.vref);
    vref = adc_chars.vref;
  }
  float voltageb = analogRead(36) / 4096 * 6.566 * (vref / 1000);
  if (voltageb > 1 ) {
    Serial.println("\nvoltage = " + String(voltageb));
    percentage = 2836.9625 * pow(voltageb, 4) - 43987.4889 * pow(voltageb, 3) + 255233.8134 * pow(voltageb, 2) - 656689.7123 * voltageb + 632041.7303;
    if (voltageb >= 4.2) percentage = 100;
    if (voltageb <= 3.8) percentage = 0;

    Serial.print((String(percentage) + "%  " + String(voltageb, 1) + "v"));
  }
  Serial.println(" ");
  Serial.println(analogRead(36));
  Serial.print(voltageb);
  Serial.println(" V");
  Serial.print(percentage);
  Serial.println(" %");





  framebuffer = (uint8_t *)ps_calloc(sizeof(uint8_t), EPD_WIDTH * EPD_HEIGHT / 2);
  if (!framebuffer) {
    Serial.println("alloc memory failed !!!");
    while (1);
  }
  memset(framebuffer, 0xFF, EPD_WIDTH * EPD_HEIGHT / 2);


  epd_poweron();

  epd_poweron();
  epd_clear_area_cycles(ConnectArea, 3, 250);
  DisplayTimeDate();
  cursor_x = 230;
  cursor_y = 20;
  writeln((GFXfont *)&OpenSans10B, "Probiha pripojovani k WiFi", &cursor_x, &cursor_y, NULL);
  epd_poweroff();


  I2CBME.begin(I2C_SDA, I2C_SCL, 9766);


  Serial.print("Joining failed ");
  Serial.print(FAILcount);
  Serial.println(" times");
  if (FAILcount < 5) {

  }
  else {
    FAILcount = 0;
    epd_clear_area_cycles(ConnectArea, 3, 250);
    FAILsleeptimer = FAILsleep;

    cursor_x = 230;
    cursor_y = 20;
    writeln((GFXfont *)&OpenSans10B, "Nepodarilo se pripojit.", &cursor_x, &cursor_y, NULL);
    cursor_x = 230;
    cursor_y = 40;

    dtostrf(FAILsleeptimer, 6, 0, failsleep);
    writeln((GFXfont *)&OpenSans10B, "Za", &cursor_x, &cursor_y, NULL);
    writeln((GFXfont *)&OpenSans10B, failsleep, &cursor_x, &cursor_y, NULL);
    writeln((GFXfont *)&OpenSans10B, " minut zkusim znovu", &cursor_x, &cursor_y, NULL);

    DisplayTime();
    DisplayTimeDate();
    epd_poweroff();
    FAILdata = 1;
    FAILsleeptimer -= 5;

    esp_sleep_enable_timer_wakeup(5 * 1000000 * 60);
    epd_poweroff_all();
    esp_deep_sleep_start();
  }
  WiFi_Connect();
  TimeSync();
  Get_Data();
  WiFi_Disconnect();
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

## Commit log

2021-06-17 WORK ONLY ON ESP8266.
    Currently trying to port code to ESP32
2021-06-17 Flow for Node-RED
2021-09-23 Rain detector pcb
2021-10-01 NOW WORKING
    Had to change pin numbers to accomodate serial communication. after testing on breadboard IT WORKS!
2021-10-01 Added bunch of samples
2021-10-02 DHT22 sample works
2021-10-02 BH1750 sample works
2021-10-02 works on arduino uno/nano. not ESP32
2021-10-05 ML8511 for ESP32
    needed due to 3v3 logic levels
2021-11-09 I like to move it move it
    [BOM.xlsx]
2021-11-09 Start of the PCB
2021-11-23 Create Help tool.xlsx
    [Help tool.xlsx]
2021-11-23 Added Heating and Sensor turnoff
2021-11-25 Created Light sensor board
2021-11-25 Created board
2021-11-29 Moved ESP, Anemo not yet connected, implement charger
2021-12-05 Lead battery charger with 723
2021-12-07 Update
    Added charger
2021-12-29 Trying making files in kicad for easier viewing
    [Light_board.kicad_pcb, Light_board.kicad_sch]
2021-12-29 Getting ready for final update
    UV needs fixing and heating too
    [WeatherStation_Main.ino]
2022-01-11 Prepairing for heating
2022-01-12 Heating works
    Only cleanup remains
2022-01-17 Working.
    Heating system yet not coded properly in.
2022-01-22 Not working fix for BMP280
    [WeatherStation_Main.ino]
2022-01-29 Repaired heatindex
2022-01-29 Clearing up and sorting stuff
    [BOM.xlsx, Light_board.kicad_pcb, Light_board.kicad_sch]
2022-02-26 Trying KiCad
    [Main_board.kicad_pcb, Main_board.kicad_sch]
2022-03-02 Creating/modifying PCB and Schematic
    [Home_Unit_OLED.kicad_pcb, Home_Unit_OLED.kicad_sch, Light_board.kicad_sch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]
2022-03-06 Added longer sleep and fixed long date overflow
    [WeatherStation_Home_Unit-E-INK.ino]
2022-03-06 Solving bug with DHT22
    [WeatherStation_Main.ino]
2022-03-20 Another update
    [Light_board.kicad_sch, Main_board.csv, Main_board.kicad_sch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]
2022-03-24 Added heating on start
2022-03-30 Added 3d printable files
    [Anemometr - Kryt.3mf, Anemometr - Lopatka.3mf, Anemometr - Tělo.3mf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]
2022-08-29 Added heat index to EInk display
